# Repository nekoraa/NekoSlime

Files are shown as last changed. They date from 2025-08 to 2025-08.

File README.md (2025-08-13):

# **NekoSlime VR Motion Capture System**

English | [中文](README.zh-CN.md) 

---

## **1. Project Overview**

This project is based on **ESP32 + BMI160 + AK09911C** sensors, compatible with the **SlimeVR protocol**, enabling full-body tracking and virtual reality interaction.

---

## **2. Bill of Materials**

| Item | Quantity | Image |
| --- | --- | --- |
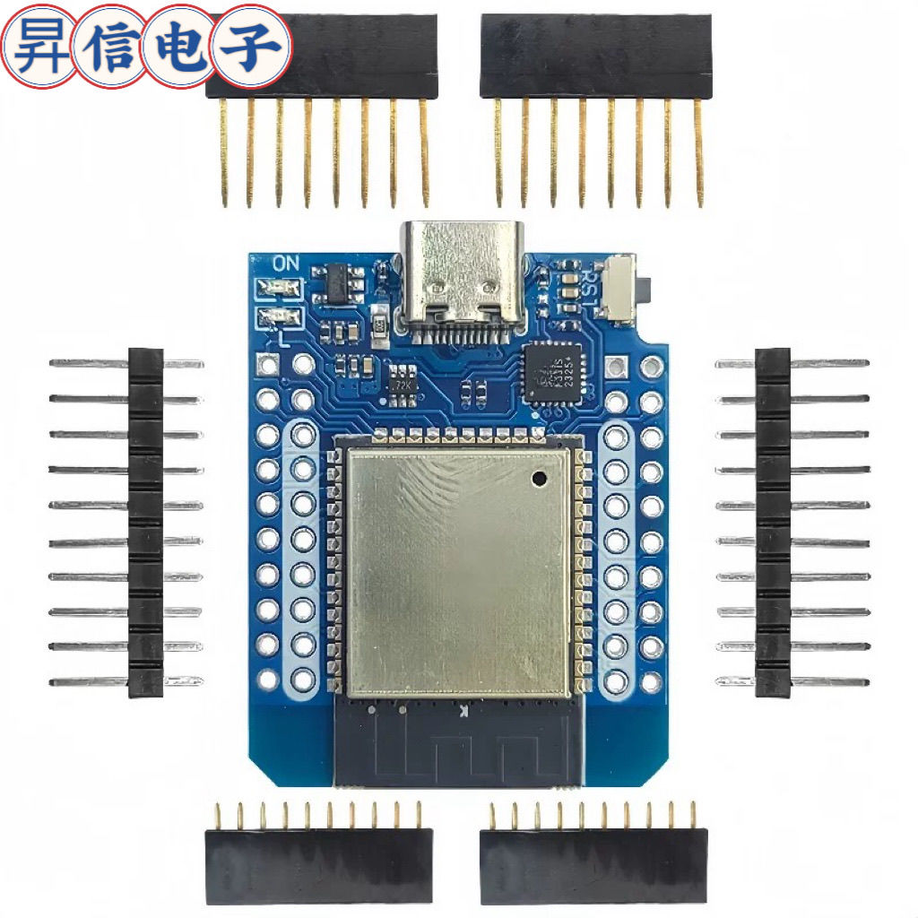
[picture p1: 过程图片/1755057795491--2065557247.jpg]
| ESP32 Mini Board | 6 |  |
| Wires for Soldering | Several  | - |
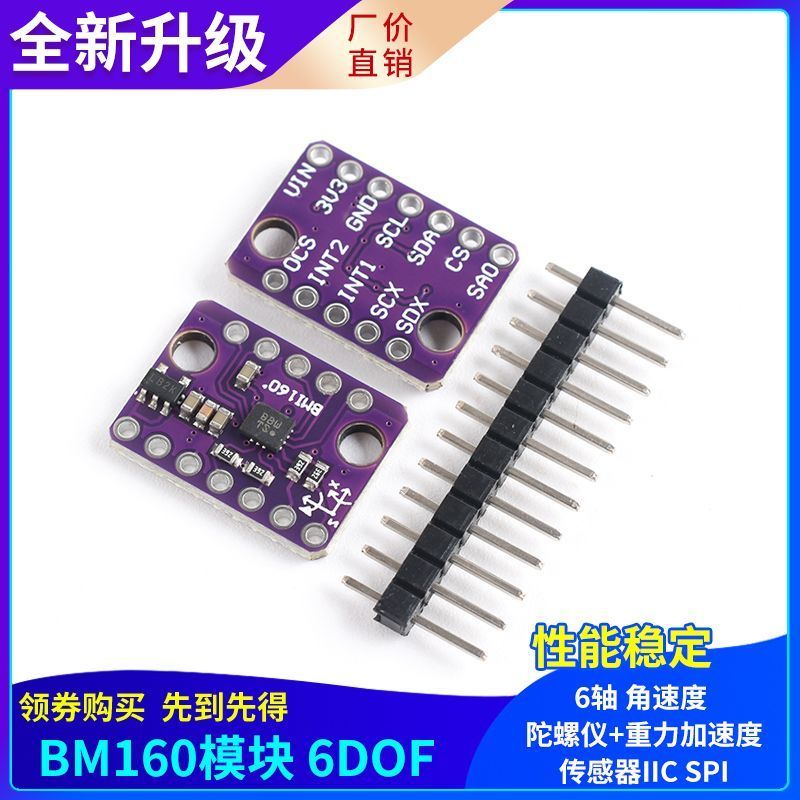
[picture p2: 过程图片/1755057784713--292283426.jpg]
| BMI160 Sensor | 5 |   |
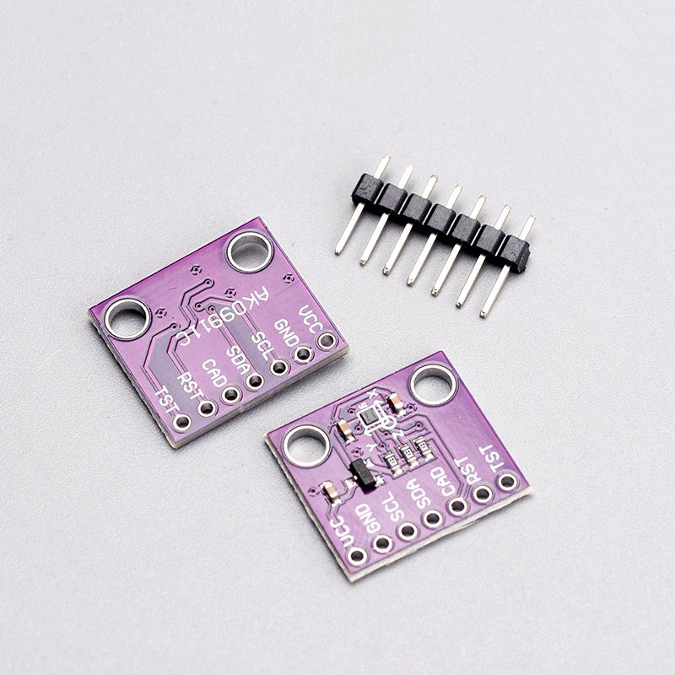
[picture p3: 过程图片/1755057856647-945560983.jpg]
| AK09911C Sensor | 5 |  |
| 3D Printed Case | 5 | - |
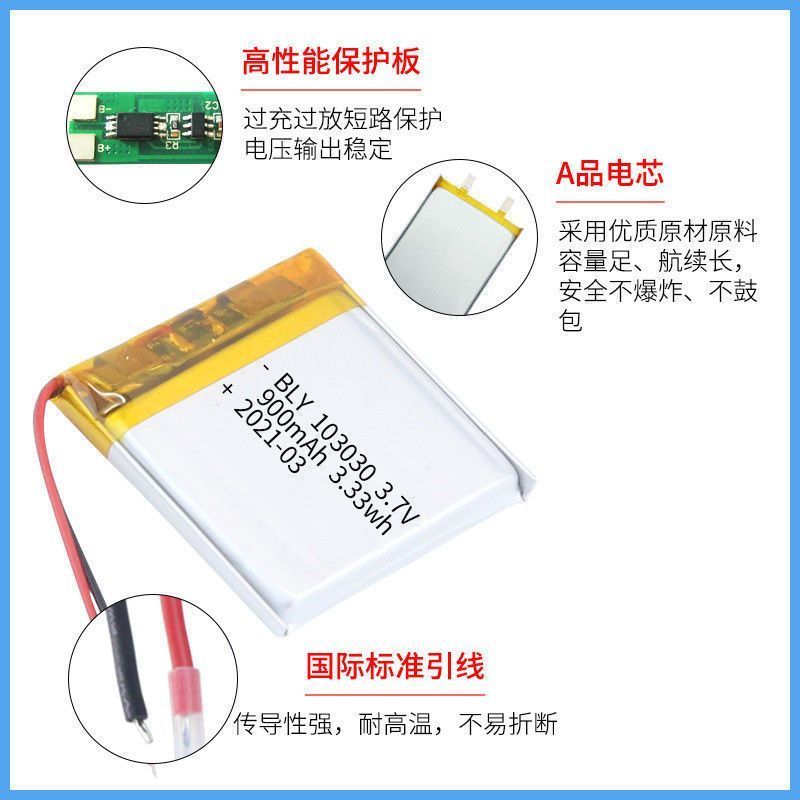
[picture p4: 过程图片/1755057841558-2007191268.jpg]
| Battery | 5 |   |
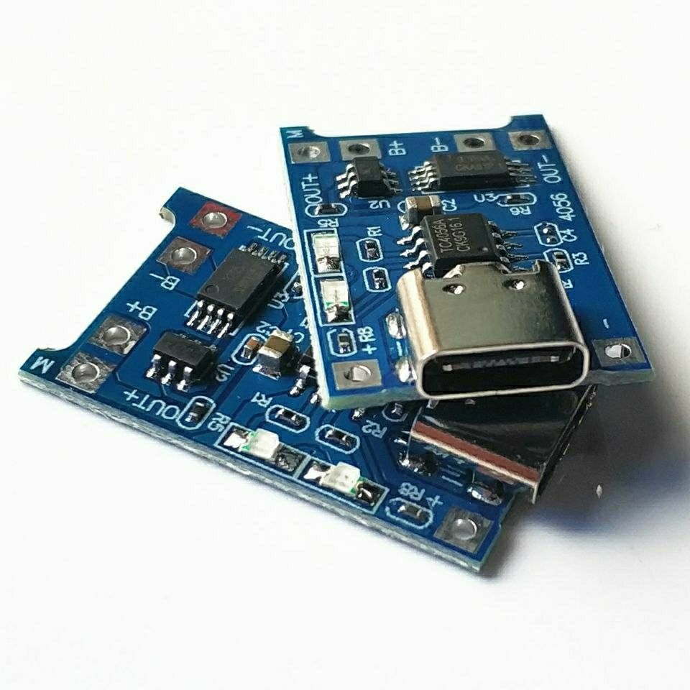
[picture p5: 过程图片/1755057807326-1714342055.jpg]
| Charging Module | 5 |   |
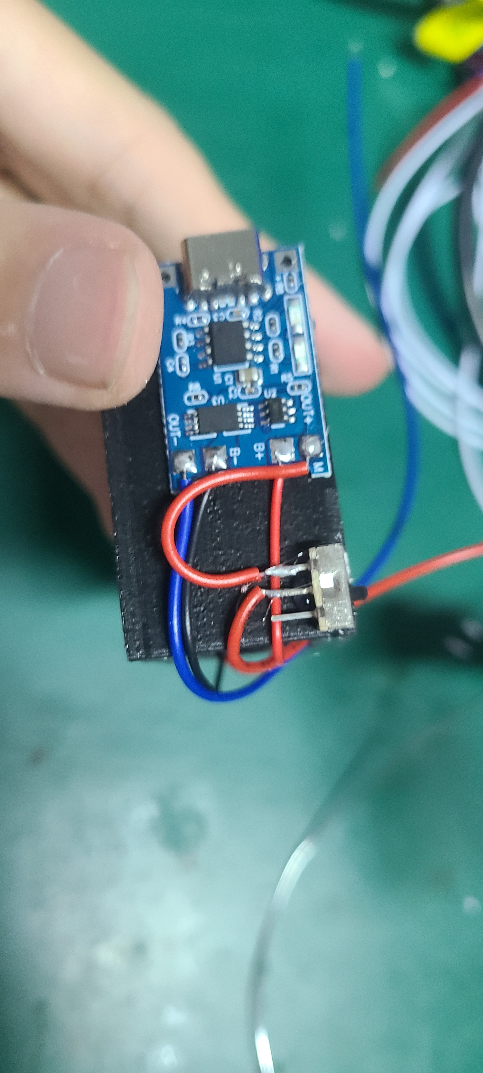
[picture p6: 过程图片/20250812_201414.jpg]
| Switch | 5 |  |

---

## **3. Hardware Connection Steps**

> ⚠ **Note**: The sensors must be aligned strictly as shown in the example to ensure consistent orientation. It is recommended to use thinner jumper wires for easier wiring.

### **3.1 Battery and Charging Module**

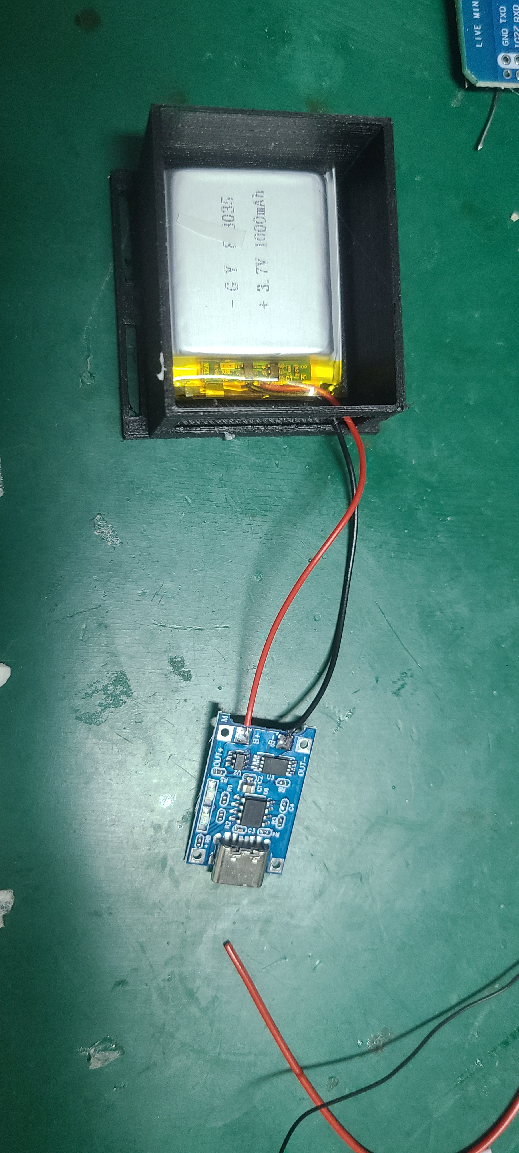
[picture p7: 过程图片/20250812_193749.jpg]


---

### **3.2 Sensor Placement**

* Fix the **BMI160** sensor on the **upper back side of the ESP32** using double-sided tape.
* All sensors must be aligned neatly.

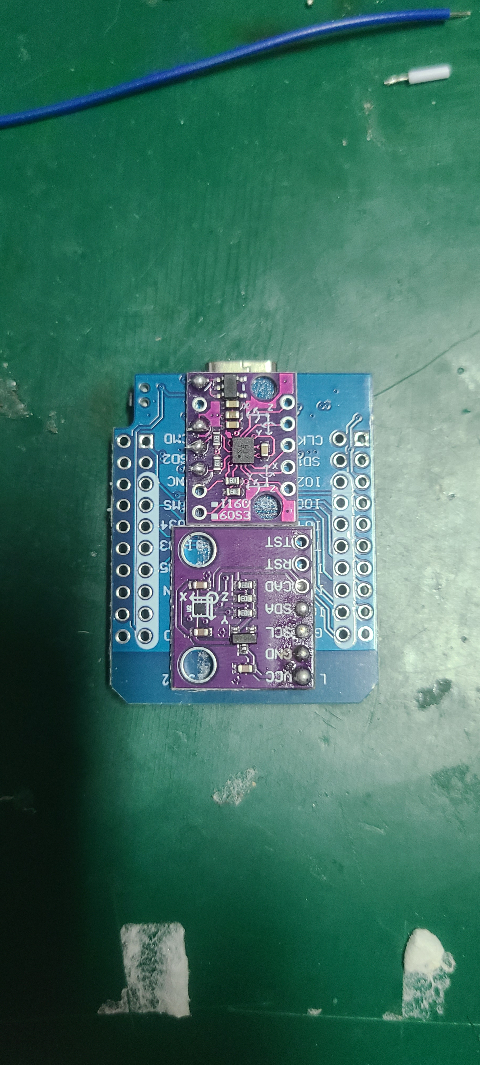
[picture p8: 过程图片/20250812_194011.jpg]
  

---

### **3.3 Sensor Wiring**

1. Connect BMI160 VCC

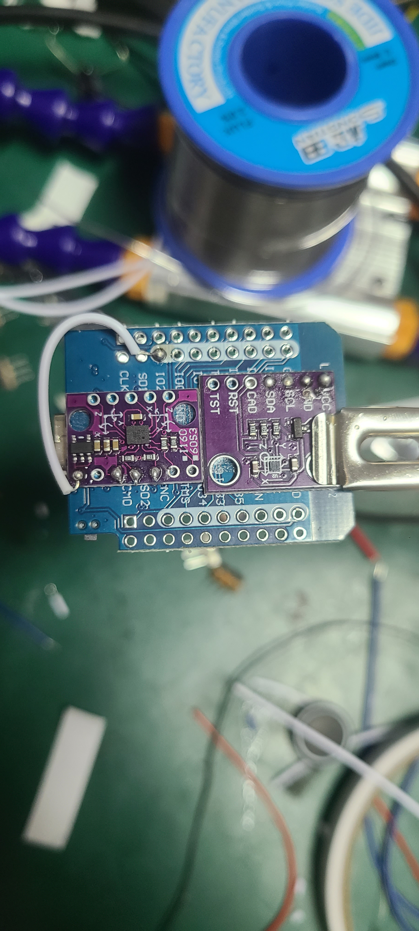
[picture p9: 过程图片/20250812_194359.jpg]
   

2. Connect BMI160 GND

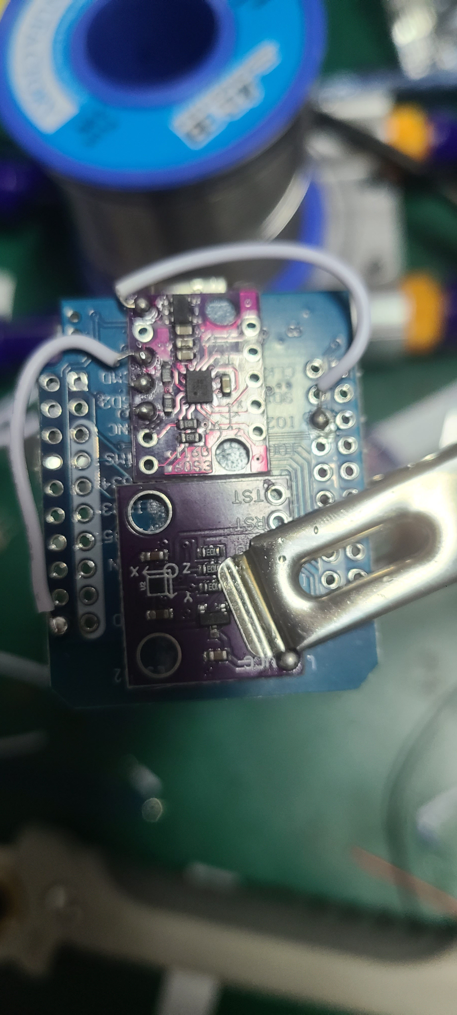
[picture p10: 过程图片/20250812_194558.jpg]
   

3. Connect BMI160 SCL

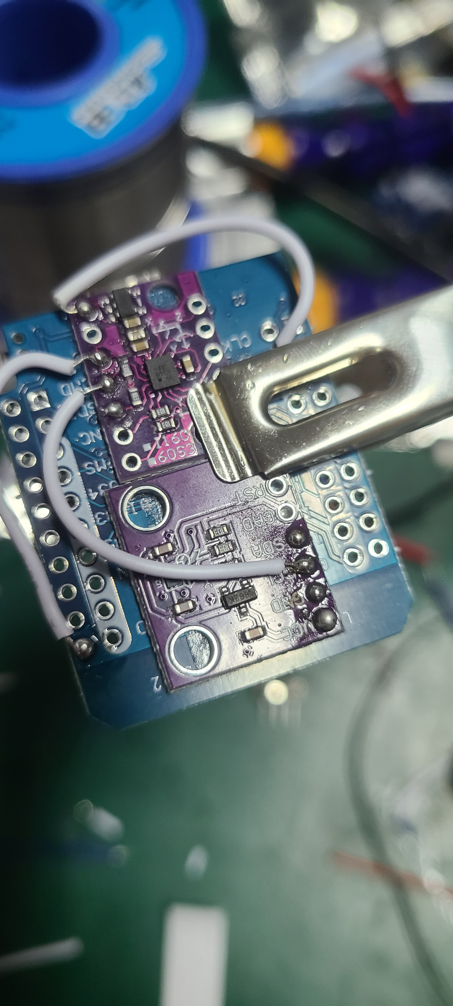
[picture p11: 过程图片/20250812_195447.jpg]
   

4. Connect BMI160 SDA

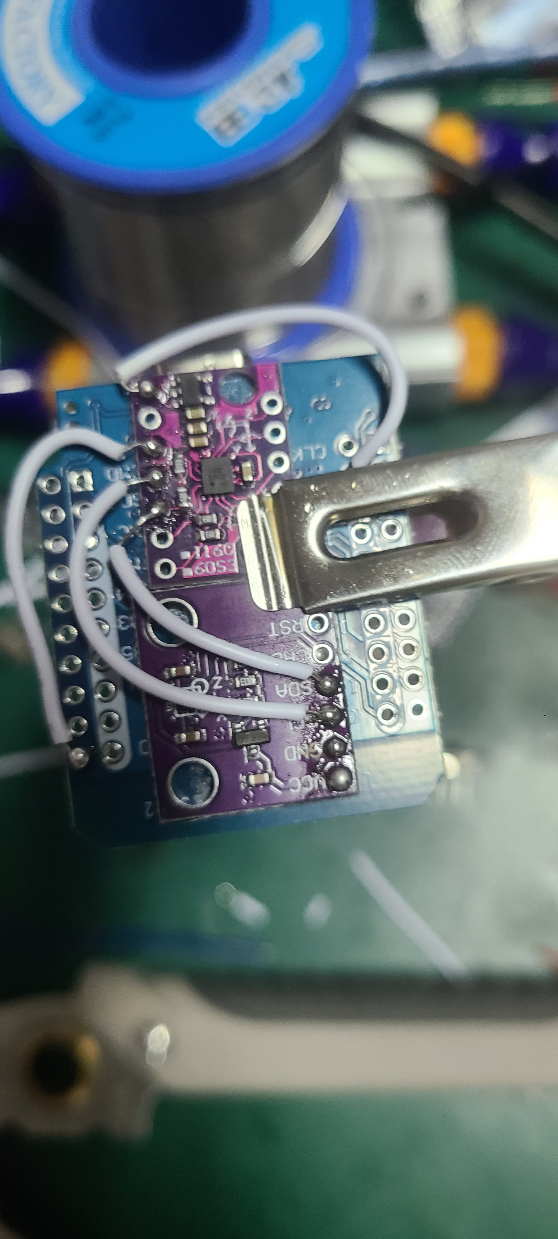
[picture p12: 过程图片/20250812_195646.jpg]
   

5. Connect AK09911C GND

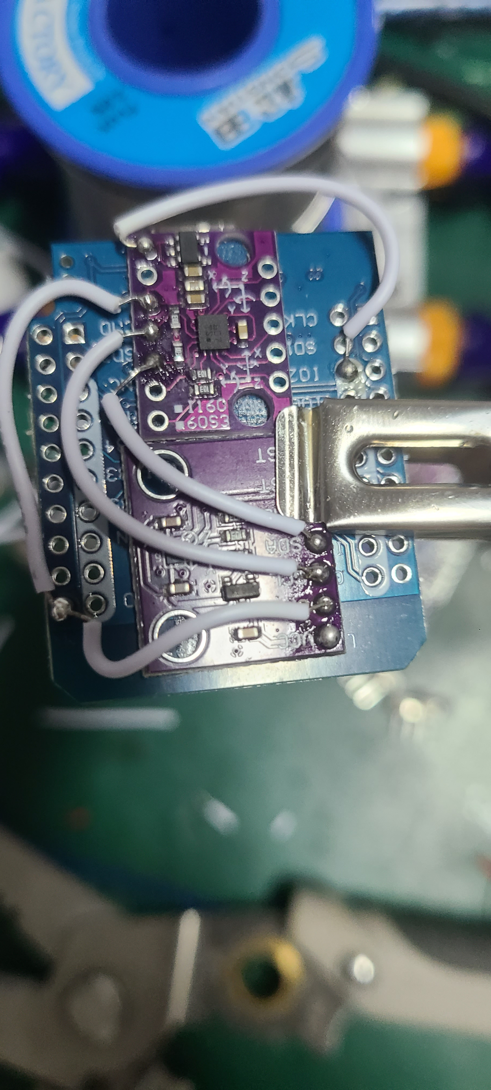
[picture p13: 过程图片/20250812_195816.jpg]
   

6. Connect SCL and SDA to ESP32 GPIO21 (SCL) and GPIO22 (SDA) respectively

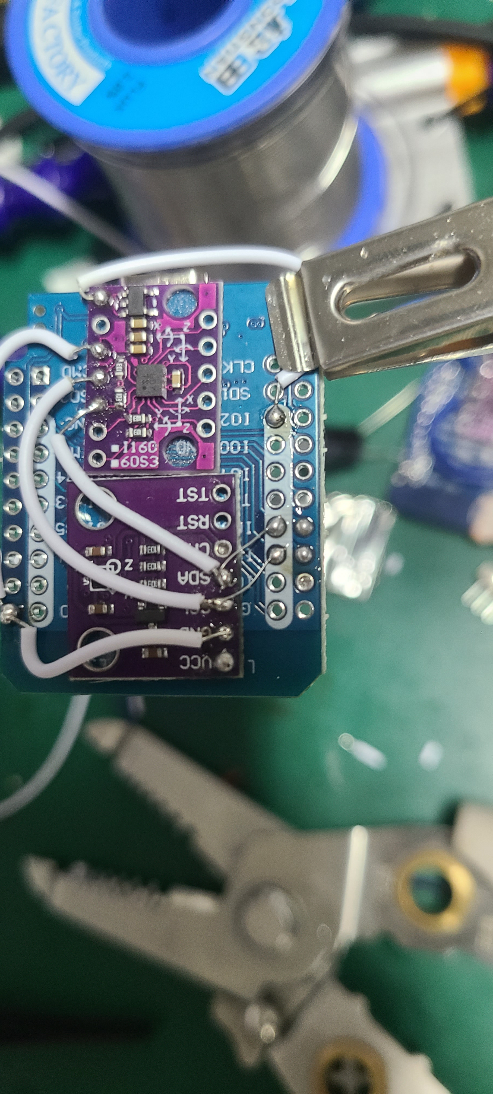
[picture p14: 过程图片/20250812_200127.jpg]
   

7. Connect AK09911C VCC

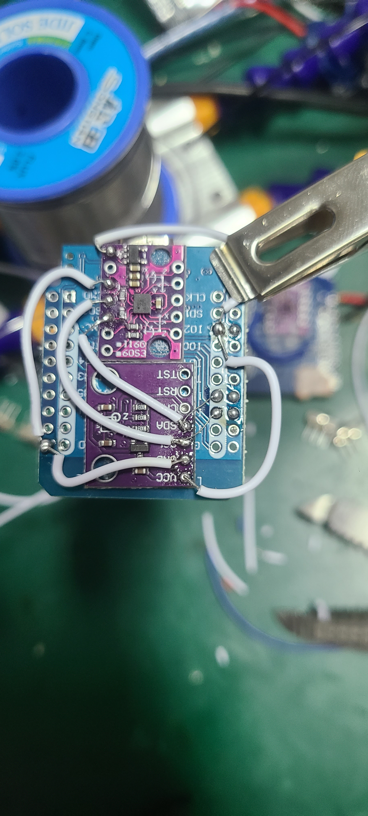
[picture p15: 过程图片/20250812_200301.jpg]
   

8. Connect AK09911C RST to ESP32 3.3V (Very important; otherwise, sensor will not work)

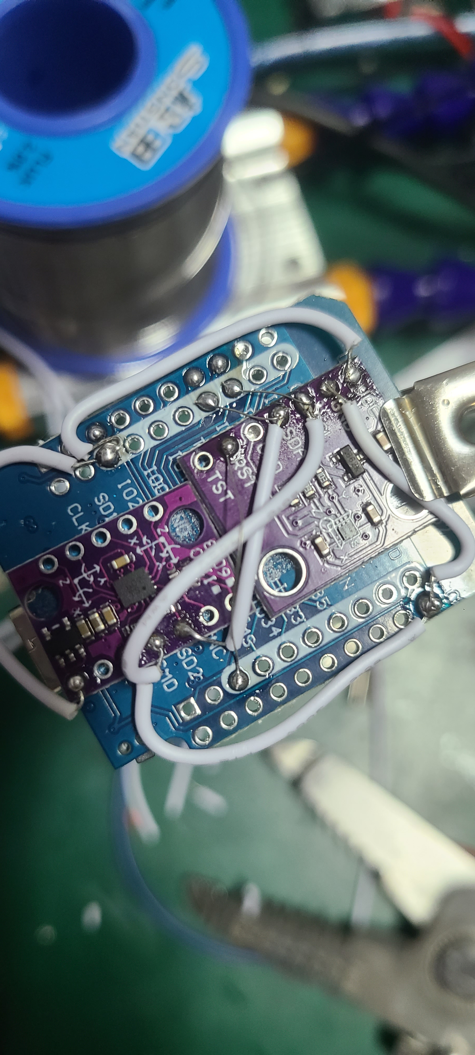
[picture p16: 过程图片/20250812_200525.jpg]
   

---

### **3.4 Final Assembly Check**

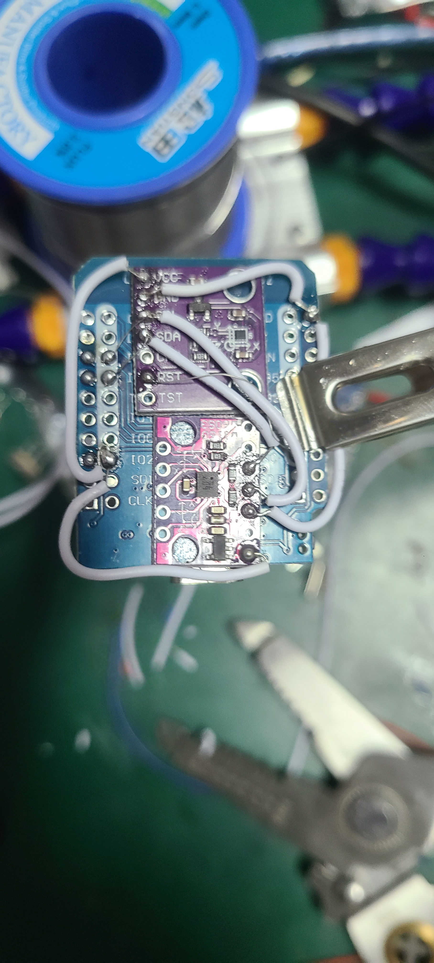
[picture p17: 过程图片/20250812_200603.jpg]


---

### **3.5 Switch and Battery Connection**

* Connect as shown in the picture

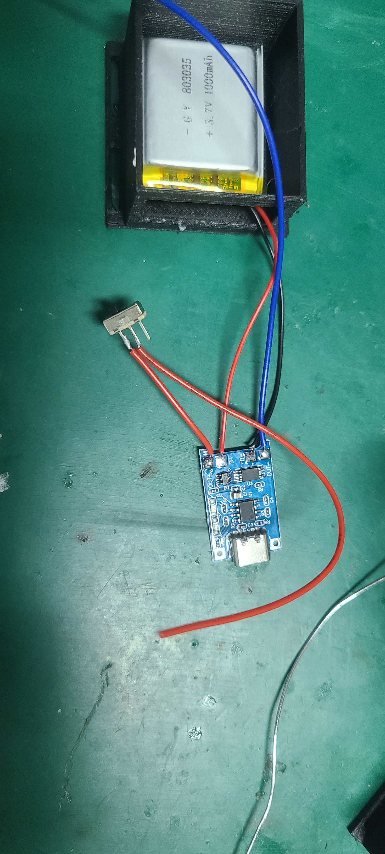
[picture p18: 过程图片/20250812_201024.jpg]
  

---

### **3.6 Fixing the Board**

* Fix the board flat and securely with hot glue as shown

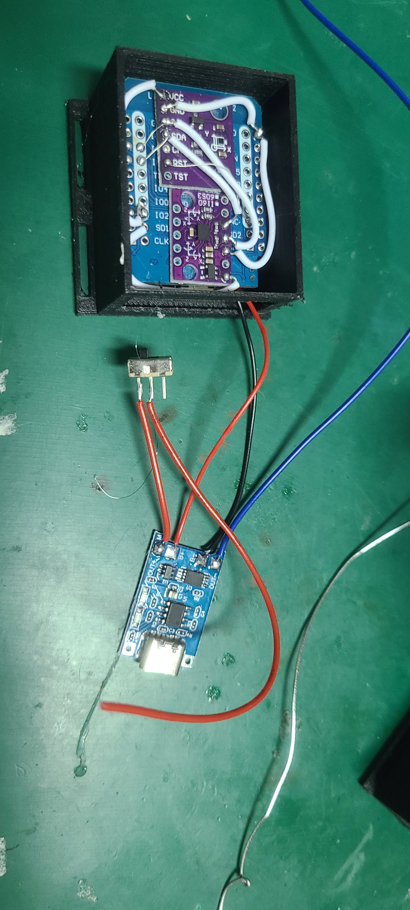
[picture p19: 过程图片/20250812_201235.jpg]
  

---

### **3.7 Charging Module**

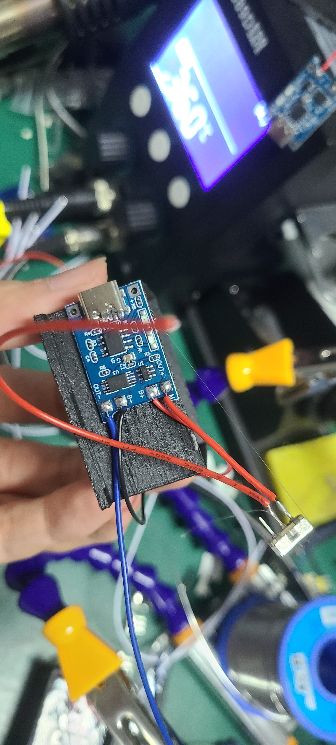
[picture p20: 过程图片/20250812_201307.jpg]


---

### **3.8 Switch**



---

### **3.9 Wiring Red and Blue Wires**

1. Pass red and blue wires through the case

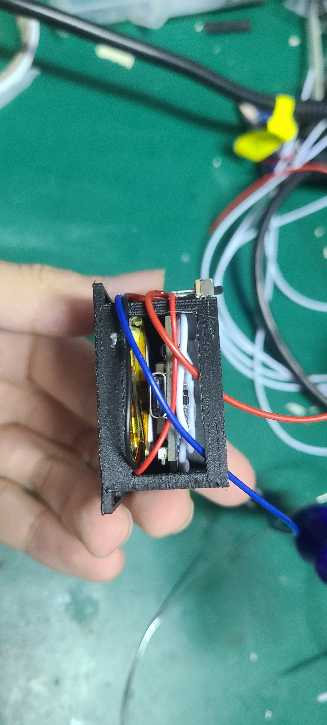
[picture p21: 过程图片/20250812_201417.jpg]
   

2. Connect blue wire to GND

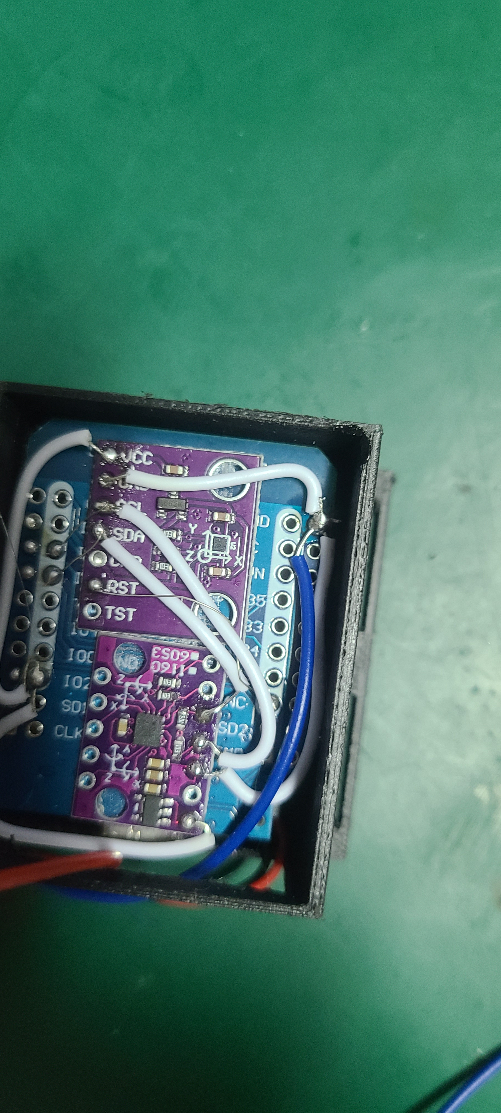
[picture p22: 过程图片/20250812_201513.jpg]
   

3. Connect red wire to VCC

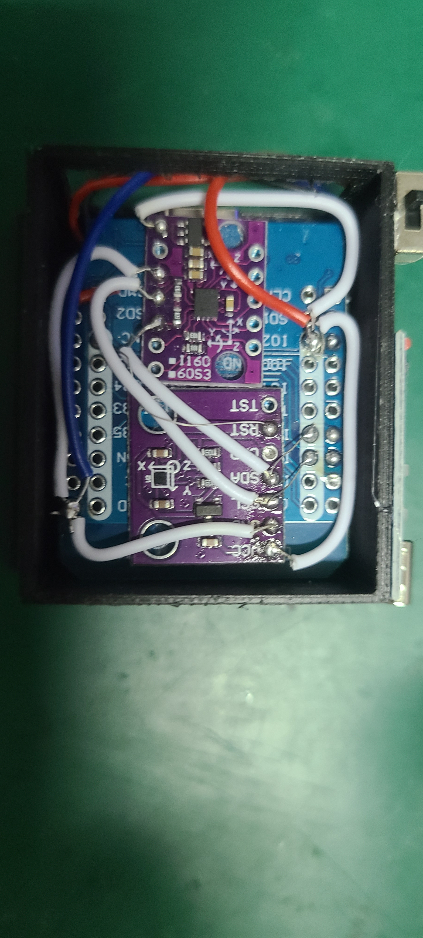
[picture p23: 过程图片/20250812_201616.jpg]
   

---

### **3.10 Complete One Unit**

* Make **6 sets** this way (1 host + 5 slaves)

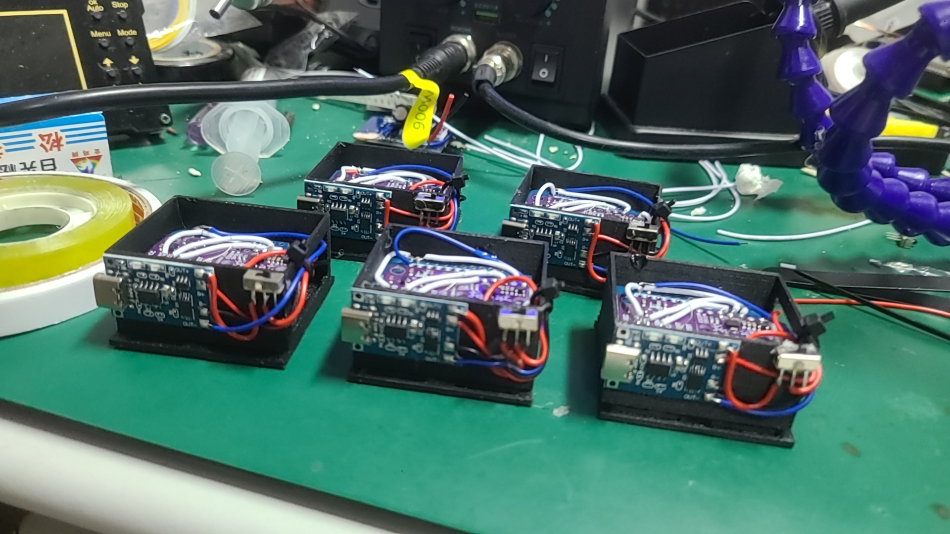
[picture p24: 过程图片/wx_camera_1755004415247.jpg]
  

---

## **4. Firmware Installation**

### **4.1 Install MicroPython**

1. Download and install [Thonny IDE](https://thonny.org/)
2. Download MicroPython firmware ([Download Link](https://micropython.org/download/))

   * Choose **ESP32** version and download the latest stable `.bin` file
3. Connect ESP32 to PC
4. Configure Thonny interpreter:

   * Tools → Options → Interpreter → Select “MicroPython (ESP32)”
   * Select the corresponding COM port
5. Flash the firmware:

   * Click “Install or update MicroPython”
   * Select `.bin` file and flash
6. Repeat for all 6 ESP32s

---

### **4.2 Host ESP32 Setup**

1. Open `host_main.py`
2. Modify Wi-Fi and PC connection settings:

```python
WIFI_SSID = "YourWiFiName"
WIFI_PASSWORD = "YourWiFiPassword"
PC_IP = "PC LAN IP"
PC_PORT = 12345
```

3. Upload `host_main.py` to host ESP32

---

### **4.3 Slave ESP32 Setup**

1. Upload the following files to each slave:

```
ak09911.py
bmi160.py
boot.py
fusion.py
main.py
```

2. Modify `TRACKER_ID` in `main.py` for each slave (0\~4)

---

## **5. PC Software Installation and Usage**

1. Ensure Python is installed on your PC
2. Run:

   * Script: `NekoSlimeReceiver.py`
   * Executable: `dist/NekoSlimeReceiver.exe`
3. Usage order:

   1. Turn on all ESP32 devices
   2. Each slave performs calibration: when blue LED flashes twice, place sensor flat for 10s, then blue LED flashes three times and enters magnetic calibration; move sensor in figure-8 pattern, then LED flashes 4 times and stays on.
   3. Start SlimeVR server
   4. Run NekoSlime receiver and click “Connect”
   5. Check if trackers are connected successfully in SlimeVR

---
# **NekoSlime VR モーションキャプチャーシステム**
---

## **1. プロジェクト概要**

本プロジェクトは **ESP32 + BMI160 + AK09911C** センサーをベースにしており、**SlimeVR プロトコル**に対応し、全身のトラッキングとVRインタラクションを実現します。

---

## **2. 部品リスト**

| 品目 | 数量 | 画像 |
| --- | -- | --- |
| ESP32 ミニボード | 6  |  |
| はんだ付け用ワイヤー | 適量 | - |
| BMI160 センサー | 5  |   |
| AK09911C センサー | 5  |  |
| 3Dプリントケース | 5  | - |
| バッテリー | 5  |   |
| 充電モジュール | 5  |   |
| スイッチ | 5  |  |

---

## **3. ハードウェア接続手順**

> ⚠ **注意**：センサーは必ずサンプルの向きに揃えて取り付けてください。向きが揃っていないと正しい動作ができません。細めのジャンパーワイヤーを使うことを推奨します。

### **3.1 バッテリーと充電モジュール**



---

### **3.2 センサーの配置**

* **BMI160** センサーを **ESP32の背面上部**に両面テープで固定します。
* センサーはすべて綺麗に揃えて配置してください。

  

---

### **3.3 センサー配線**

1. BMI160 VCC を接続

   

2. BMI160 GND を接続

   

3. BMI160 SCL を接続

   

4. BMI160 SDA を接続

   

5. AK09911C GND を接続

   

6. SCL と SDA をそれぞれ ESP32 の GPIO21（SCL）と GPIO22（SDA）に接続

   

7. AK09911C VCC を接続

   

8. AK09911C RST を ESP32 の 3.3V に接続（非常に重要。接続しないと動作しません）

   

---

### **3.4 全体の組み立て確認**



---

### **3.5 スイッチとバッテリーの接続**

* 写真のように接続してください

  

---

### **3.6 ボードの固定**

* ボードは平らにし、ホットボンドでしっかり固定してください。

  

---

### **3.7 充電モジュール**



---

### **3.8 スイッチ**



---

### **3.9 赤と青の配線**

1. 赤と青の線をケースの中に通します。

   

2. 青線をGNDに接続

   

3. 赤線をVCCに接続

   

---

### **3.10 1セット完成**

* この方法で **6セット** 作成してください（1台はホスト、5台はスレーブ）

  

---

## **4. ファームウェアのインストール**

### **4.1 MicroPythonのインストール**

1. [Thonny IDE](https://thonny.org/) をダウンロード・インストール
2. MicroPythonファームウェアをダウンロード（[リンク](https://micropython.org/download/)）

   * **ESP32** 用の最新版の `.bin` ファイルを選択
3. ESP32をPCに接続
4. Thonnyでインタプリタを設定：

   * ツール → オプション → インタプリタ → “MicroPython (ESP32)” を選択
   * 対応するCOMポートを選択
5. ファームウェアを書き込み：

   * “Install or update MicroPython” をクリック
   * `.bin` ファイルを選択して書き込み
6. 6台すべてのESP32で繰り返し

---

### **4.2 ホストESP32の設定**

1. `host_main.py` を開く
2. Wi-FiおよびPC接続設定を変更：

```python
WIFI_SSID = "あなたのWiFi名"
WIFI_PASSWORD = "あなたのWiFiパスワード"
PC_IP = "PCのLAN IPアドレス"
PC_PORT = 12345
```

3. `host_main.py` をホストESP32にアップロード

---

### **4.3 スレーブESP32の設定**

1. 各スレーブに以下のファイルをアップロード：

```
ak09911.py
bmi160.py
boot.py
fusion.py
main.py
```

2. `main.py` 内の `TRACKER_ID` をそれぞれ異なる値（0〜4）に設定

---

## **5. PCソフトのインストールと実行**

1. PCにPythonがインストールされていることを確認
2. 実行方法：

   * スクリプト：`NekoSlimeReceiver.py`
   * 実行ファイル：`dist/NekoSlimeReceiver.exe`
3. 実行手順：

   1. 全てのESP32を電源オン
   2. スレーブはキャリブレーションを実行：青LEDが2回点滅したらセンサーを平置きで10秒間待つ。次に青LEDが3回点滅し、磁気キャリブレーションへ移行。8の字を描くように動かし、完了するとLEDが4回点滅して点灯状態になる。
   3. SlimeVRサーバーを起動
   4. NekoSlime受信プログラムを起動し「接続」ボタンを押す
   5. SlimeVRでトラッカーが接続されているか確認する

---

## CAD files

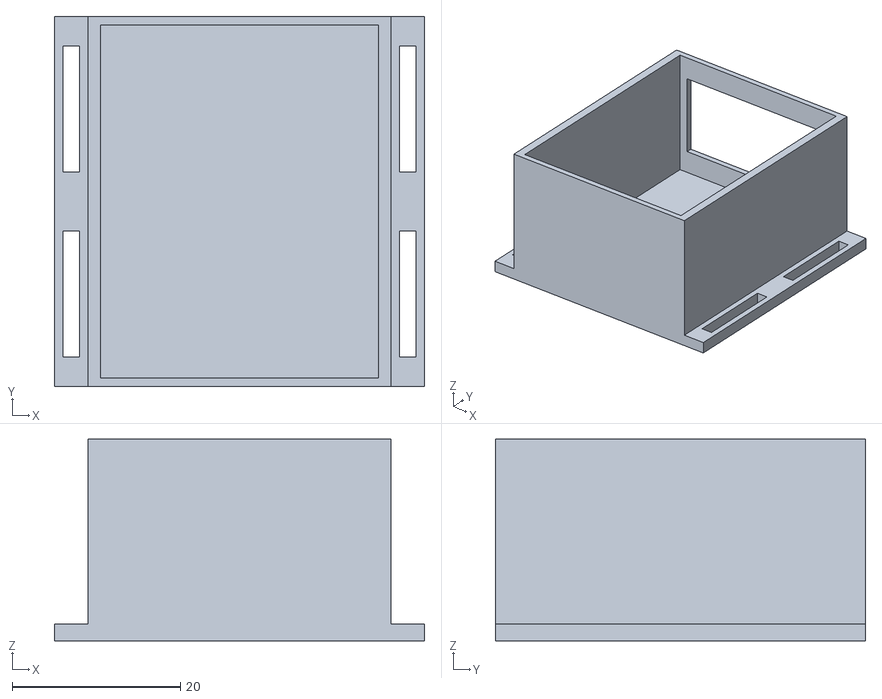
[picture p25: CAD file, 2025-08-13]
零件1.STL
44.0 x 44.0 x 24.0

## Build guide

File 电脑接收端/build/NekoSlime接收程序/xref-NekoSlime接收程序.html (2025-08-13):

# modulegraph cross reference for NekoSlime接收程序.py, pyi_rth__tkinter.py, pyi_rth_inspect.py

NekoSlime接收程序.py Script

imports: _collections_abc • _weakrefset • abc • codecs • collections • collections.abc • copyreg • encodings • encodings.aliases • encodings.ascii • encodings.base64_codec • encodings.big5 • encodings.big5hkscs • encodings.bz2_codec • encodings.charmap • encodings.cp037 • encodings.cp1006 • encodings.cp1026 • encodings.cp1125 • encodings.cp1140 • encodings.cp1250 • encodings.cp1251 • encodings.cp1252 • encodings.cp1253 • encodings.cp1254 • encodings.cp1255 • encodings.cp1256 • encodings.cp1257 • encodings.cp1258 • encodings.cp273 • encodings.cp424 • encodings.cp437 • encodings.cp500 • encodings.cp720 • encodings.cp737 • encodings.cp775 • encodings.cp850 • encodings.cp852 • encodings.cp855 • encodings.cp856 • encodings.cp857 • encodings.cp858 • encodings.cp860 • encodings.cp861 • encodings.cp862 • encodings.cp863 • encodings.cp864 • encodings.cp865 • encodings.cp866 • encodings.cp869 • encodings.cp874 • encodings.cp875 • encodings.cp932 • encodings.cp949 • encodings.cp950 • encodings.euc_jis_2004 • encodings.euc_jisx0213 • encodings.euc_jp • encodings.euc_kr • encodings.gb18030 • encodings.gb2312 • encodings.gbk • encodings.hex_codec • encodings.hp_roman8 • encodings.hz • encodings.idna • encodings.iso2022_jp • encodings.iso2022_jp_1 • encodings.iso2022_jp_2 • encodings.iso2022_jp_2004 • encodings.iso2022_jp_3 • encodings.iso2022_jp_ext • encodings.iso2022_kr • encodings.iso8859_1 • encodings.iso8859_10 • encodings.iso8859_11 • encodings.iso8859_13 • encodings.iso8859_14 • encodings.iso8859_15 • encodings.iso8859_16 • encodings.iso8859_2 • encodings.iso8859_3 • encodings.iso8859_4 • encodings.iso8859_5 • encodings.iso8859_6 • encodings.iso8859_7 • encodings.iso8859_8 • encodings.iso8859_9 • encodings.johab • encodings.koi8_r • encodings.koi8_t • encodings.koi8_u • encodings.kz1048 • encodings.latin_1 • encodings.mac_arabic • encodings.mac_croatian • encodings.mac_cyrillic • encodings.mac_farsi • encodings.mac_greek • encodings.mac_iceland • encodings.mac_latin2 • encodings.mac_roman • encodings.mac_romanian • encodings.mac_turkish • encodings.mbcs • encodings.oem • encodings.palmos • encodings.ptcp154 • encodings.punycode • encodings.quopri_codec • encodings.raw_unicode_escape • encodings.rot_13 • encodings.shift_jis • encodings.shift_jis_2004 • encodings.shift_jisx0213 • encodings.tis_620 • encodings.undefined • encodings.unicode_escape • encodings.utf_16 • encodings.utf_16_be • encodings.utf_16_le • encodings.utf_32 • encodings.utf_32_be • encodings.utf_32_le • encodings.utf_7 • encodings.utf_8 • encodings.utf_8_sig • encodings.uu_codec • encodings.zlib_codec • enum • functools • genericpath • heapq • io • keyword • linecache • locale • ntpath • operator • os • posixpath • pyi_rth__tkinter.py • pyi_rth_inspect.py • re • re._casefix • re._compiler • re._constants • re._parser • reprlib • socket • sre_compile • sre_constants • sre_parse • stat • struct • threading • time • tkinter • tkinter.messagebox • tkinter.ttk • traceback • types • warnings • weakref

pyi_rth__tkinter.py Script

imports: os • sys

imported by: NekoSlime接收程序.py

pyi_rth_inspect.py Script

imports: inspect • os • sys • zipfile

imported by: NekoSlime接收程序.py

_abc (builtin module)

imported by: abc

_ast (builtin module)

imported by: ast

_bisect (builtin module)

imported by: bisect

_blake2 (builtin module)

imported by: hashlib

_bz2 C:\Users\Administrator\.conda\envs\pcb绘制\DLLs\_bz2.pyd

imported by: bz2

_codecs (builtin module)

imported by: codecs

_codecs_cn (builtin module)

imported by: encodings.gb18030 • encodings.gb2312 • encodings.gbk • encodings.hz

_codecs_hk (builtin module)

imported by: encodings.big5hkscs

_codecs_iso2022 (builtin module)

imported by: encodings.iso2022_jp • encodings.iso2022_jp_1 • encodings.iso2022_jp_2 • encodings.iso2022_jp_2004 • encodings.iso2022_jp_3 • encodings.iso2022_jp_ext • encodings.iso2022_kr

_codecs_jp (builtin module)

imported by: encodings.cp932 • encodings.euc_jis_2004 • encodings.euc_jisx0213 • encodings.euc_jp • encodings.shift_jis • encodings.shift_jis_2004 • encodings.shift_jisx0213

_codecs_kr (builtin module)

imported by: encodings.cp949 • encodings.euc_kr • encodings.johab

_codecs_tw (builtin module)

imported by: encodings.big5 • encodings.cp950

_collections (builtin module)

imported by: collections • threading

_collections_abc SourceModule

imports: abc • sys • warnings

imported by: NekoSlime接收程序.py • collections • collections.abc • contextlib • locale • os • pathlib • random • types • weakref

_compat_pickle SourceModule

imported by: _pickle • pickle

_compression SourceModule

imports: io • sys

imported by: bz2 • gzip • lzma

_contextvars (builtin module)

imported by: contextvars

_csv (builtin module)

imported by: csv

_datetime (builtin module)

imports: _strptime • time

imported by: datetime

_decimal C:\Users\Administrator\.conda\envs\pcb绘制\DLLs\_decimal.pyd

imported by: decimal

_frozen_importlib ExcludedModule

imported by: importlib • importlib.abc

_frozen_importlib_external MissingModule

imported by: importlib • importlib._bootstrap • importlib.abc

_functools (builtin module)

imported by: functools

_hashlib C:\Users\Administrator\.conda\envs\pcb绘制\DLLs\_hashlib.pyd

imported by: hashlib

_heapq (builtin module)

imported by: heapq

_imp (builtin module)

imported by: importlib • importlib._bootstrap_external • importlib.util

_io (builtin module)

imported by: importlib._bootstrap_external • io

_locale (builtin module)

imported by: locale

_lzma C:\Users\Administrator\.conda\envs\pcb绘制\DLLs\_lzma.pyd

imported by: lzma

_md5 (builtin module)

imported by: hashlib

_multibytecodec (builtin module)

imported by: encodings.big5 • encodings.big5hkscs • encodings.cp932 • encodings.cp949 • encodings.cp950 • encodings.euc_jis_2004 • encodings.euc_jisx0213 • encodings.euc_jp • encodings.euc_kr • encodings.gb18030 • encodings.gb2312 • encodings.gbk • encodings.hz • encodings.iso2022_jp • encodings.iso2022_jp_1 • encodings.iso2022_jp_2 • encodings.iso2022_jp_2004 • encodings.iso2022_jp_3 • encodings.iso2022_jp_ext • encodings.iso2022_kr • encodings.johab • encodings.shift_jis • encodings.shift_jis_2004 • encodings.shift_jisx0213

_opcode (builtin module)

imported by: opcode

_operator (builtin module)

imported by: operator

_pickle (builtin module)

imports: _compat_pickle • codecs • copyreg

imported by: pickle

_posixsubprocess MissingModule

imports: gc

imported by: subprocess

_py_abc SourceModule

imports: _weakrefset

imported by: abc

_pydatetime SourceModule

imports: _strptime • math • operator • sys • time • warnings

imported by: datetime

_pydecimal SourceModule

imports: collections • contextvars • itertools • locale • math • numbers • re • sys

imported by: decimal

_random (builtin module)

imported by: random

_sha1 (builtin module)

imported by: hashlib

_sha2 (builtin module)

imported by: hashlib • random

_sha3 (builtin module)

imported by: hashlib

_signal (builtin module)

imported by: signal

_socket C:\Users\Administrator\.conda\envs\pcb绘制\DLLs\_socket.pyd

imported by: socket

_sre (builtin module)

imports: copy • re

imported by: re • re._compiler • re._constants

_stat (builtin module)

imported by: stat

_statistics (builtin module)

imported by: statistics

_string (builtin module)

imported by: string

_strptime SourceModule

imports: _thread • calendar • datetime • locale • re • time

imported by: _datetime • _pydatetime • time

_struct (builtin module)

imported by: struct

_thread (builtin module)

imported by: _strptime • dataclasses • functools • reprlib • tempfile • threading

_threading_local SourceModule

imports: contextlib • threading • weakref

imported by: threading

_tkinter C:\Users\Administrator\.conda\envs\pcb绘制\DLLs\_tkinter.pyd

imported by: tkinter

_tokenize (builtin module)

imported by: tokenize

_tracemalloc (builtin module)

imported by: tracemalloc

_typing (builtin module)

imported by: typing

_warnings (builtin module)

imported by: importlib._bootstrap_external • warnings

_weakref (builtin module)

imported by: _weakrefset • collections • weakref

_weakrefset SourceModule

imports: _weakref • types

imported by: NekoSlime接收程序.py • _py_abc • threading • weakref

_winapi (builtin module)

imported by: encodings • ntpath • shutil • subprocess

abc SourceModule

imports: _abc • _py_abc

imported by: NekoSlime接收程序.py • _collections_abc • contextlib • dataclasses • email._policybase • functools • importlib._abc • importlib.abc • importlib.metadata • importlib.resources.abc • inspect • io • numbers • os • selectors • typing

argparse SourceModule

imports: copy • gettext • os • re • shutil • sys • textwrap • warnings

imported by: ast • calendar • dis • gzip • inspect • py_compile • tarfile • tokenize • zipfile

array (builtin module)

imported by: socket

ast SourceModule

imports: _ast • argparse • collections • contextlib • enum • inspect • re • sys • warnings

imported by: inspect • traceback

atexit (builtin module)

imported by: logging • weakref

base64 SourceModule

imports: binascii • getopt • re • struct • sys

imported by: email._encoded_words • email.base64mime • email.encoders • encodings.base64_codec

binascii (builtin module)

imported by: base64 • email._encoded_words • email.base64mime • email.contentmanager • email.header • email.message • encodings.hex_codec • encodings.uu_codec • quopri • zipfile

bisect SourceModule

imports: _bisect

imported by: random • statistics

builtins (builtin module)

imported by: bz2 • codecs • enum • gettext • gzip • inspect • locale • lzma • operator • reprlib • subprocess • tarfile • tokenize • warnings

bz2 SourceModule

imports: _bz2 • _compression • builtins • io • os

imported by: encodings.bz2_codec • shutil • tarfile • zipfile

calendar SourceModule

imports: argparse • datetime • enum • itertools • locale • sys • warnings

imported by: _strptime • email._parseaddr

codecs SourceModule

imports: _codecs • builtins • encodings • sys

imported by: NekoSlime接收程序.py • _pickle • encodings • encodings.ascii • encodings.base64_codec • encodings.big5 • encodings.big5hkscs • encodings.bz2_codec • encodings.charmap • encodings.cp037 • encodings.cp1006 • encodings.cp1026 • encodings.cp1125 • encodings.cp1140 • encodings.cp1250 • encodings.cp1251 • encodings.cp1252 • encodings.cp1253 • encodings.cp1254 • encodings.cp1255 • encodings.cp1256 • encodings.cp1257 • encodings.cp1258 • encodings.cp273 • encodings.cp424 • encodings.cp437 • encodings.cp500 • encodings.cp720 • encodings.cp737 • encodings.cp775 • encodings.cp850 • encodings.cp852 • encodings.cp855 • encodings.cp856 • encodings.cp857 • encodings.cp858 • encodings.cp860 • encodings.cp861 • encodings.cp862 • encodings.cp863 • encodings.cp864 • encodings.cp865 • encodings.cp866 • encodings.cp869 • encodings.cp874 • encodings.cp875 • encodings.cp932 • encodings.cp949 • encodings.cp950 • encodings.euc_jis_2004 • encodings.euc_jisx0213 • encodings.euc_jp • encodings.euc_kr • encodings.gb18030 • encodings.gb2312 • encodings.gbk • encodings.hex_codec • encodings.hp_roman8 • encodings.hz • encodings.idna • encodings.iso2022_jp • encodings.iso2022_jp_1 • encodings.iso2022_jp_2 • encodings.iso2022_jp_2004 • encodings.iso2022_jp_3 • encodings.iso2022_jp_ext • encodings.iso2022_kr • encodings.iso8859_1 • encodings.iso8859_10 • encodings.iso8859_11 • encodings.iso8859_13 • encodings.iso8859_14 • encodings.iso8859_15 • encodings.iso8859_16 • encodings.iso8859_2 • encodings.iso8859_3 • encodings.iso8859_4 • encodings.iso8859_5 • encodings.iso8859_6 • encodings.iso8859_7 • encodings.iso8859_8 • encodings.iso8859_9 • encodings.johab • encodings.koi8_r • encodings.koi8_t • encodings.koi8_u • encodings.kz1048 • encodings.latin_1 • encodings.mac_arabic • encodings.mac_croatian • encodings.mac_cyrillic • encodings.mac_farsi • encodings.mac_greek • encodings.mac_iceland • encodings.mac_latin2 • encodings.mac_roman • encodings.mac_romanian • encodings.mac_turkish • encodings.mbcs • encodings.oem • encodings.palmos • encodings.ptcp154 • encodings.punycode • encodings.quopri_codec • encodings.raw_unicode_escape • encodings.rot_13 • encodings.shift_jis • encodings.shift_jis_2004 • encodings.shift_jisx0213 • encodings.tis_620 • encodings.undefined • encodings.unicode_escape • encodings.utf_16 • encodings.utf_16_be • encodings.utf_16_le • encodings.utf_32 • encodings.utf_32_be • encodings.utf_32_le • encodings.utf_7 • encodings.utf_8 • encodings.utf_8_sig • encodings.uu_codec • encodings.zlib_codec • pickle • tokenize

collections Package

imports: _collections • _collections_abc • _weakref • copy • heapq • itertools • keyword • operator • reprlib • sys

imported by: NekoSlime接收程序.py • _pydecimal • ast • collections.abc • contextlib • dis • email.feedparser • functools • importlib.metadata • importlib.metadata._collections • importlib.resources.readers • inspect • pprint • selectors • shutil • statistics • string • threading • tkinter • tokenize • typing • urllib.parse

collections.abc SourceModule

imports: _collections_abc • collections

imported by: NekoSlime接收程序.py • inspect • logging • selectors • traceback • tracemalloc • typing

contextlib SourceModule

imports: _collections_abc • abc • collections • functools • os • sys • types

imported by: _threading_local • ast • importlib.metadata • importlib.resources._adapters • importlib.resources._common • subprocess • traceback • typing • zipfile._path

contextvars SourceModule

imports: _contextvars

imported by: _pydecimal

copy SourceModule

imports: copyreg • types • weakref

imported by: _sre • argparse • collections • dataclasses • email.generator • gettext • tarfile • weakref

copyreg SourceModule

imports: functools • operator

imported by: NekoSlime接收程序.py • _pickle • copy • pickle • re • typing

csv SourceModule

imports: _csv • io • re • types

imported by: importlib.metadata

dataclasses SourceModule

imports: _thread • abc • copy • functools • inspect • itertools • keyword • re • sys • types

imported by: pprint

datetime SourceModule

imports: _datetime • _pydatetime • time

imported by: _strptime • calendar • email.utils

decimal SourceModule

imports: _decimal • _pydecimal

imported by: fractions • statistics

dis SourceModule

imports: argparse • collections • io • opcode • sys • types

imported by: inspect

email Package

imports: email._header_value_parser • email.charset • email.errors • email.header • email.parser

imported by: email._encoded_words • email._header_value_parser • email._parseaddr • email._policybase • email.base64mime • email.charset • email.contentmanager • email.encoders • email.errors • email.feedparser • email.generator • email.header • email.headerregistry • email.iterators • email.message • email.parser • email.policy • email.quoprimime • email.utils • importlib.metadata

email._encoded_words SourceModule

imports: base64 • binascii • email • email.errors • functools • re • string

imported by: email._header_value_parser • email.message

email._header_value_parser SourceModule

imports: email • email._encoded_words • email.errors • email.utils • operator • re • string • sys • urllib

imported by: email • email.headerregistry

email._parseaddr SourceModule

imports: calendar • email • time

imported by: email.utils

email._policybase SourceModule

imports: abc • email • email.charset • email.header • email.utils

imported by: email.feedparser • email.message • email.parser • email.policy

email.base64mime SourceModule

imports: base64 • binascii • email

imported by: email.charset • email.header

email.charset SourceModule

imports: email • email.base64mime • email.encoders • email.errors • email.quoprimime • functools

imported by: email • email._policybase • email.contentmanager • email.header • email.message • email.utils

email.contentmanager SourceModule

imports: binascii • email • email.charset • email.errors • email.message • email.quoprimime

imported by: email.policy

email.encoders SourceModule

imports: base64 • email • quopri

imported by: email.charset

email.errors SourceModule

imports: email

imported by: email • email._encoded_words • email._header_value_parser • email.charset • email.contentmanager • email.feedparser • email.generator • email.header • email.headerregistry • email.message

email.feedparser SourceModule

imports: collections • email • email._policybase • email.errors • email.message • io • re

imported by: email.parser

email.generator SourceModule

imports: copy • email • email.errors • email.utils • io • random • re • sys • time

imported by: email.message

email.header SourceModule

imports: binascii • email • email.base64mime • email.charset • email.errors • email.quoprimime • re

imported by: email • email._policybase

email.headerregistry SourceModule

imports: email • email._header_value_parser • email.errors • email.utils • types

imported by: email.policy

email.iterators SourceModule

imports: email • io • sys

imported by: email.message

email.message SourceModule

imports: binascii • email • email._encoded_words • email._policybase • email.charset • email.errors • email.generator • email.iterators • email.policy • email.utils • io • quopri • re

imported by: email.contentmanager • email.feedparser • email.policy • importlib.metadata._adapters

email.parser SourceModule

imports: email • email._policybase • email.feedparser • io

imported by: email

email.policy SourceModule

imports: email • email._policybase • email.contentmanager • email.headerregistry • email.message • email.utils • re • sys

imported by: email.message

email.quoprimime SourceModule

imports: email • re • string

imported by: email.charset • email.contentmanager • email.header

email.utils SourceModule

imports: datetime • email • email._parseaddr • email.charset • os • random • re • socket • time • urllib.parse • warnings

imported by: email._header_value_parser • email._policybase • email.generator • email.headerregistry • email.message • email.policy

encodings Package

imports: _winapi • codecs • encodings • encodings.aliases • encodings.ascii • encodings.base64_codec • encodings.big5 • encodings.big5hkscs • encodings.bz2_codec • encodings.charmap • encodings.cp037 • encodings.cp1006 • encodings.cp1026 • encodings.cp1125 • encodings.cp1140 • encodings.cp1250 • encodings.cp1251 • encodings.cp1252 • encodings.cp1253 • encodings.cp1254 • encodings.cp1255 • encodings.cp1256 • encodings.cp1257 • encodings.cp1258 • encodings.cp273 • encodings.cp424 • encodings.cp437 • encodings.cp500 • encodings.cp720 • encodings.cp737 • encodings.cp775 • encodings.cp850 • encodings.cp852 • encodings.cp855 • encodings.cp856 • encodings.cp857 • encodings.cp858 • encodings.cp860 • encodings.cp861 • encodings.cp862 • encodings.cp863 • encodings.cp864 • encodings.cp865 • encodings.cp866 • encodings.cp869 • encodings.cp874 • encodings.cp875 • encodings.cp932 • encodings.cp949 • encodings.cp950 • encodings.euc_jis_2004 • encodings.euc_jisx0213 • encodings.euc_jp • encodings.euc_kr • encodings.gb18030 • encodings.gb2312 • encodings.gbk • encodings.hex_codec • encodings.hp_roman8 • encodings.hz • encodings.idna • encodings.iso2022_jp • encodings.iso2022_jp_1 • encodings.iso2022_jp_2 • encodings.iso2022_jp_2004 • encodings.iso2022_jp_3 • encodings.iso2022_jp_ext • encodings.iso2022_kr • encodings.iso8859_1 • encodings.iso8859_10 • encodings.iso8859_11 • encodings.iso8859_13 • encodings.iso8859_14 • encodings.iso8859_15 • encodings.iso8859_16 • encodings.iso8859_2 • encodings.iso8859_3 • encodings.iso8859_4 • encodings.iso8859_5 • encodings.iso8859_6 • encodings.iso8859_7 • encodings.iso8859_8 • encodings.iso8859_9 • encodings.johab • encodings.koi8_r • encodings.koi8_t • encodings.koi8_u • encodings.kz1048 • encodings.latin_1 • encodings.mac_arabic • encodings.mac_croatian • encodings.mac_cyrillic • encodings.mac_farsi • encodings.mac_greek • encodings.mac_iceland • encodings.mac_latin2 • encodings.mac_roman • encodings.mac_romanian • encodings.mac_turkish • encodings.mbcs • encodings.oem • encodings.palmos • encodings.ptcp154 • encodings.punycode • encodings.quopri_codec • encodings.raw_unicode_escape • encodings.rot_13 • encodings.shift_jis • encodings.shift_jis_2004 • encodings.shift_jisx0213 • encodings.tis_620 • encodings.undefined • encodings.unicode_escape • encodings.utf_16 • encodings.utf_16_be • encodings.utf_16_le • encodings.utf_32 • encodings.utf_32_be • encodings.utf_32_le • encodings.utf_7 • encodings.utf_8 • encodings.utf_8_sig • encodings.uu_codec • encodings.zlib_codec • sys

imported by: NekoSlime接收程序.py • codecs • encodings • encodings.aliases • encodings.ascii • encodings.base64_codec • encodings.big5 • encodings.big5hkscs • encodings.bz2_codec • encodings.charmap • encodings.cp037 • encodings.cp1006 • encodings.cp1026 • encodings.cp1125 • encodings.cp1140 • encodings.cp1250 • encodings.cp1251 • encodings.cp1252 • encodings.cp1253 • encodings.cp1254 • encodings.cp1255 • encodings.cp1256 • encodings.cp1257 • encodings.cp1258 • encodings.cp273 • encodings.cp424 • encodings.cp437 • encodings.cp500 • encodings.cp720 • encodings.cp737 • encodings.cp775 • encodings.cp850 • encodings.cp852 • encodings.cp855 • encodings.cp856 • encodings.cp857 • encodings.cp858 • encodings.cp860 • encodings.cp861 • encodings.cp862 • encodings.cp863 • encodings.cp864 • encodings.cp865 • encodings.cp866 • encodings.cp869 • encodings.cp874 • encodings.cp875 • encodings.cp932 • encodings.cp949 • encodings.cp950 • encodings.euc_jis_2004 • encodings.euc_jisx0213 • encodings.euc_jp • encodings.euc_kr • encodings.gb18030 • encodings.gb2312 • encodings.gbk • encodings.hex_codec • encodings.hp_roman8 • encodings.hz • encodings.idna • encodings.iso2022_jp • encodings.iso2022_jp_1 • encodings.iso2022_jp_2 • encodings.iso2022_jp_2004 • encodings.iso2022_jp_3 • encodings.iso2022_jp_ext • encodings.iso2022_kr • encodings.iso8859_1 • encodings.iso8859_10 • encodings.iso8859_11 • encodings.iso8859_13 • encodings.iso8859_14 • encodings.iso8859_15 • encodings.iso8859_16 • encodings.iso8859_2 • encodings.iso8859_3 • encodings.iso8859_4 • encodings.iso8859_5 • encodings.iso8859_6 • encodings.iso8859_7 • encodings.iso8859_8 • encodings.iso8859_9 • encodings.johab • encodings.koi8_r • encodings.koi8_t • encodings.koi8_u • encodings.kz1048 • encodings.latin_1 • encodings.mac_arabic • encodings.mac_croatian • encodings.mac_cyrillic • encodings.mac_farsi • encodings.mac_greek • encodings.mac_iceland • encodings.mac_latin2 • encodings.mac_roman • encodings.mac_romanian • encodings.mac_turkish • encodings.mbcs • encodings.oem • encodings.palmos • encodings.ptcp154 • encodings.punycode • encodings.quopri_codec • encodings.raw_unicode_escape • encodings.rot_13 • encodings.shift_jis • encodings.shift_jis_2004 • encodings.shift_jisx0213 • encodings.tis_620 • encodings.undefined • encodings.unicode_escape • encodings.utf_16 • encodings.utf_16_be • encodings.utf_16_le • encodings.utf_32 • encodings.utf_32_be • encodings.utf_32_le • encodings.utf_7 • encodings.utf_8 • encodings.utf_8_sig • encodings.uu_codec • encodings.zlib_codec • locale

encodings.aliases SourceModule

imports: encodings

imported by: NekoSlime接收程序.py • encodings • locale

encodings.ascii SourceModule

imports: codecs • encodings

imported by: NekoSlime接收程序.py • encodings

encodings.base64_codec SourceModule

imports: base64 • codecs • encodings

imported by: NekoSlime接收程序.py • encodings

encodings.big5 SourceModule

imports: _codecs_tw • _multibytecodec • codecs • encodings

imported by: NekoSlime接收程序.py • encodings

encodings.big5hkscs SourceModule

imports: _codecs_hk • _multibytecodec • codecs • encodings

imported by: NekoSlime接收程序.py • encodings

encodings.bz2_codec SourceModule

imports: bz2 • codecs • encodings

imported by: NekoSlime接收程序.py • encodings

encodings.charmap SourceModule

imports: codecs • encodings

imported by: NekoSlime接收程序.py • encodings

encodings.cp037 SourceModule

imports: codecs • encodings

imported by: NekoSlime接收程序.py • encodings

encodings.cp1006 SourceModule

imports: codecs • encodings

imported by: NekoSlime接收程序.py • encodings

encodings.cp1026 SourceModule

imports: codecs • encodings

imported by: NekoSlime接收程序.py • encodings

encodings.cp1125 SourceModule

imports: codecs • encodings

imported by: NekoSlime接收程序.py • encodings

encodings.cp1140 SourceModule

imports: codecs • encodings

imported by: NekoSlime接收程序.py • encodings

encodings.cp1250 SourceModule

imports: codecs • encodings

imported by: NekoSlime接收程序.py • encodings

encodings.cp1251 SourceModule

imports: codecs • encodings

imported by: NekoSlime接收程序.py • encodings

encodings.cp1252 SourceModule

imports: codecs • encodings

imported by: NekoSlime接收程序.py • encodings

encodings.cp1253 SourceModule

imports: codecs • encodings

imported by: NekoSlime接收程序.py • encodings

encodings.cp1254 SourceModule

imports: codecs • encodings

imported by: NekoSlime接收程序.py • encodings

encodings.cp1255 SourceModule

imports: codecs • encodings

imported by: NekoSlime接收程序.py • encodings

encodings.cp1256 SourceModule

imports: codecs • encodings

imported by: NekoSlime接收程序.py • encodings

encodings.cp1257 SourceModule

imports: codecs • encodings

imported by: NekoSlime接收程序.py • encodings

encodings.cp1258 SourceModule

imports: codecs • encodings

imported by: NekoSlime接收程序.py • encodings

encodings.cp273 SourceModule

imports: codecs • encodings

imported by: NekoSlime接收程序.py • encodings

encodings.cp424 SourceModule

imports: codecs • encodings

imported by: NekoSlime接收程序.py • encodings

encodings.cp437 SourceModule

imports: codecs • encodings

imported by: NekoSlime接收程序.py • encodings

encodings.cp500 SourceModule

imports: codecs • encodings

imported by: NekoSlime接收程序.py • encodings

encodings.cp720 SourceModule

imports: codecs • encodings

imported by: NekoSlime接收程序.py • encodings

encodings.cp737 SourceModule

imports: codecs • encodings

imported by: NekoSlime接收程序.py • encodings

encodings.cp775 SourceModule

imports: codecs • encodings

imported by: NekoSlime接收程序.py • encodings

encodings.cp850 SourceModule

imports: codecs • encodings

imported by: NekoSlime接收程序.py • encodings

encodings.cp852 SourceModule

imports: codecs • encodings

imported by: NekoSlime接收程序.py • encodings

encodings.cp855 SourceModule

imports: codecs • encodings

imported by: NekoSlime接收程序.py • encodings

encodings.cp856 SourceModule

imports: codecs • encodings

imported by: NekoSlime接收程序.py • encodings

encodings.cp857 SourceModule

imports: codecs • encodings

imported by: NekoSlime接收程序.py • encodings

encodings.cp858 SourceModule

imports: codecs • encodings

imported by: NekoSlime接收程序.py • encodings

encodings.cp860 SourceModule

imports: codecs • encodings

imported by: NekoSlime接收程序.py • encodings

encodings.cp861 SourceModule

imports: codecs • encodings

imported by: NekoSlime接收程序.py • encodings

encodings.cp862 SourceModule

imports: codecs • encodings

imported by: NekoSlime接收程序.py • encodings

encodings.cp863 SourceModule

imports: codecs • encodings

imported by: NekoSlime接收程序.py • encodings

encodings.cp864 SourceModule

imports: codecs • encodings

imported by: NekoSlime接收程序.py • encodings

encodings.cp865 SourceModule

imports: codecs • encodings

imported by: NekoSlime接收程序.py • encodings

encodings.cp866 SourceModule

imports: codecs • encodings

imported by: NekoSlime接收程序.py • encodings

encodings.cp869 SourceModule

imports: codecs • encodings

imported by: NekoSlime接收程序.py • encodings

encodings.cp874 SourceModule

imports: codecs • encodings

imported by: NekoSlime接收程序.py • encodings

encodings.cp875 SourceModule

imports: codecs • encodings

imported by: NekoSlime接收程序.py • encodings

encodings.cp932 SourceModule

imports: _codecs_jp • _multibytecodec • codecs • encodings

imported by: NekoSlime接收程序.py • encodings

encodings.cp949 SourceModule

imports: _codecs_kr • _multibytecodec • codecs • encodings

imported by: NekoSlime接收程序.py • encodings

encodings.cp950 SourceModule

imports: _codecs_tw • _multibytecodec • codecs • encodings

imported by: NekoSlime接收程序.py • encodings

encodings.euc_jis_2004 SourceModule

imports: _codecs_jp • _multibytecodec • codecs • encodings

imported by: NekoSlime接收程序.py • encodings

encodings.euc_jisx0213 SourceModule

imports: _codecs_jp • _multibytecodec • codecs • encodings

imported by: NekoSlime接收程序.py • encodings

encodings.euc_jp SourceModule

imports: _codecs_jp • _multibytecodec • codecs • encodings

imported by: NekoSlime接收程序.py • encodings

encodings.euc_kr SourceModule

imports: _codecs_kr • _multibytecodec • codecs • encodings

imported by: NekoSlime接收程序.py • encodings

encodings.gb18030 SourceModule

imports: _codecs_cn • _multibytecodec • codecs • encodings

imported by: NekoSlime接收程序.py • encodings

encodings.gb2312 SourceModule

imports: _codecs_cn • _multibytecodec • codecs • encodings

imported by: NekoSlime接收程序.py • encodings

encodings.gbk SourceModule

imports: _codecs_cn • _multibytecodec • codecs • encodings

imported by: NekoSlime接收程序.py • encodings

encodings.hex_codec SourceModule

imports: binascii • codecs • encodings

imported by: NekoSlime接收程序.py • encodings

encodings.hp_roman8 SourceModule

imports: codecs • encodings

imported by: NekoSlime接收程序.py • encodings

encodings.hz SourceModule

imports: _codecs_cn • _multibytecodec • codecs • encodings

imported by: NekoSlime接收程序.py • encodings

encodings.idna SourceModule

imports: codecs • encodings • re • stringprep • unicodedata

imported by: NekoSlime接收程序.py • encodings

encodings.iso2022_jp SourceModule

imports: _codecs_iso2022 • _multibytecodec • codecs • encodings

imported by: NekoSlime接收程序.py • encodings

encodings.iso2022_jp_1 SourceModule

imports: _codecs_iso2022 • _multibytecodec • codecs • encodings

imported by: NekoSlime接收程序.py • encodings

encodings.iso2022_jp_2 SourceModule

imports: _codecs_iso2022 • _multibytecodec • codecs • encodings

imported by: NekoSlime接收程序.py • encodings

encodings.iso2022_jp_2004 SourceModule

imports: _codecs_iso2022 • _multibytecodec • codecs • encodings

imported by: NekoSlime接收程序.py • encodings

encodings.iso2022_jp_3 SourceModule

imports: _codecs_iso2022 • _multibytecodec • codecs • encodings

imported by: NekoSlime接收程序.py • encodings

encodings.iso2022_jp_ext SourceModule

imports: _codecs_iso2022 • _multibytecodec • codecs • encodings

imported by: NekoSlime接收程序.py • encodings

encodings.iso2022_kr SourceModule

imports: _codecs_iso2022 • _multibytecodec • codecs • encodings

imported by: NekoSlime接收程序.py • encodings

encodings.iso8859_1 SourceModule

imports: codecs • encodings

imported by: NekoSlime接收程序.py • encodings

encodings.iso8859_10 SourceModule

imports: codecs • encodings

imported by: NekoSlime接收程序.py • encodings

encodings.iso8859_11 SourceModule

imports: codecs • encodings

imported by: NekoSlime接收程序.py • encodings

encodings.iso8859_13 SourceModule

imports: codecs • encodings

imported by: NekoSlime接收程序.py • encodings

encodings.iso8859_14 SourceModule

imports: codecs • encodings

imported by: NekoSlime接收程序.py • encodings

encodings.iso8859_15 SourceModule

imports: codecs • encodings

imported by: NekoSlime接收程序.py • encodings

encodings.iso8859_16 SourceModule

imports: codecs • encodings

imported by: NekoSlime接收程序.py • encodings

encodings.iso8859_2 SourceModule

imports: codecs • encodings

imported by: NekoSlime接收程序.py • encodings

encodings.iso8859_3 SourceModule

imports: codecs • encodings

imported by: NekoSlime接收程序.py • encodings

encodings.iso8859_4 SourceModule

imports: codecs • encodings

imported by: NekoSlime接收程序.py • encodings

encodings.iso8859_5 SourceModule

imports: codecs • encodings

imported by: NekoSlime接收程序.py • encodings

encodings.iso8859_6 SourceModule

imports: codecs • encodings

imported by: NekoSlime接收程序.py • encodings

encodings.iso8859_7 SourceModule

imports: codecs • encodings

imported by: NekoSlime接收程序.py • encodings

encodings.iso8859_8 SourceModule

imports: codecs • encodings

imported by: NekoSlime接收程序.py • encodings

encodings.iso8859_9 SourceModule

imports: codecs • encodings

imported by: NekoSlime接收程序.py • encodings

encodings.johab SourceModule

imports: _codecs_kr • _multibytecodec • codecs • encodings

imported by: NekoSlime接收程序.py • encodings

encodings.koi8_r SourceModule

imports: codecs • encodings

imported by: NekoSlime接收程序.py • encodings

encodings.koi8_t SourceModule

imports: codecs • encodings

imported by: NekoSlime接收程序.py • encodings

encodings.koi8_u SourceModule

imports: codecs • encodings

imported by: NekoSlime接收程序.py • encodings

encodings.kz1048 SourceModule

imports: codecs • encodings

imported by: NekoSlime接收程序.py • encodings

encodings.latin_1 SourceModule

imports: codecs • encodings

imported by: NekoSlime接收程序.py • encodings

encodings.mac_arabic SourceModule

imports: codecs • encodings

imported by: NekoSlime接收程序.py • encodings

encodings.mac_croatian SourceModule

imports: codecs • encodings

imported by: NekoSlime接收程序.py • encodings

encodings.mac_cyrillic SourceModule

imports: codecs • encodings

imported by: NekoSlime接收程序.py • encodings

encodings.mac_farsi SourceModule

imports: codecs • encodings

imported by: NekoSlime接收程序.py • encodings

encodings.mac_greek SourceModule

imports: codecs • encodings

imported by: NekoSlime接收程序.py • encodings

encodings.mac_iceland SourceModule

imports: codecs • encodings

imported by: NekoSlime接收程序.py • encodings

encodings.mac_latin2 SourceModule

imports: codecs • encodings

imported by: NekoSlime接收程序.py • encodings

encodings.mac_roman SourceModule

imports: codecs • encodings

imported by: NekoSlime接收程序.py • encodings

encodings.mac_romanian SourceModule

imports: codecs • encodings

imported by: NekoSlime接收程序.py • encodings

encodings.mac_turkish SourceModule

imports: codecs • encodings

imported by: NekoSlime接收程序.py • encodings

encodings.mbcs SourceModule

imports: codecs • encodings

imported by: NekoSlime接收程序.py • encodings

encodings.oem SourceModule

imports: codecs • encodings

imported by: NekoSlime接收程序.py • encodings

encodings.palmos SourceModule

imports: codecs • encodings

imported by: NekoSlime接收程序.py • encodings

encodings.ptcp154 SourceModule

imports: codecs • encodings

imported by: NekoSlime接收程序.py • encodings

encodings.punycode SourceModule

imports: codecs • encodings

imported by: NekoSlime接收程序.py • encodings

encodings.quopri_codec SourceModule

imports: codecs • encodings • io • quopri

imported by: NekoSlime接收程序.py • encodings

encodings.raw_unicode_escape SourceModule

imports: codecs • encodings

imported by: NekoSlime接收程序.py • encodings

encodings.rot_13 SourceModule

imports: codecs • encodings • sys

imported by: NekoSlime接收程序.py • encodings

encodings.shift_jis SourceModule

imports: _codecs_jp • _multibytecodec • codecs • encodings

imported by: NekoSlime接收程序.py • encodings

encodings.shift_jis_2004 SourceModule

imports: _codecs_jp • _multibytecodec • codecs • encodings

imported by: NekoSlime接收程序.py • encodings

encodings.shift_jisx0213 SourceModule

imports: _codecs_jp • _multibytecodec • codecs • encodings

imported by: NekoSlime接收程序.py • encodings

encodings.tis_620 SourceModule

imports: codecs • encodings

imported by: NekoSlime接收程序.py • encodings

encodings.undefined SourceModule

imports: codecs • encodings

imported by: NekoSlime接收程序.py • encodings

encodings.unicode_escape SourceModule

imports: codecs • encodings

imported by: NekoSlime接收程序.py • encodings

encodings.utf_16 SourceModule

imports: codecs • encodings • sys

imported by: NekoSlime接收程序.py • encodings

encodings.utf_16_be SourceModule

imports: codecs • encodings

imported by: NekoSlime接收程序.py • encodings

encodings.utf_16_le SourceModule

imports: codecs • encodings

imported by: NekoSlime接收程序.py • encodings

encodings.utf_32 SourceModule

imports: codecs • encodings • sys

imported by: NekoSlime接收程序.py • encodings

encodings.utf_32_be SourceModule

imports: codecs • encodings

imported by: NekoSlime接收程序.py • encodings

encodings.utf_32_le SourceModule

imports: codecs • encodings

imported by: NekoSlime接收程序.py • encodings

encodings.utf_7 SourceModule

imports: codecs • encodings

imported by: NekoSlime接收程序.py • encodings

encodings.utf_8 SourceModule

imports: codecs • encodings

imported by: NekoSlime接收程序.py • encodings

encodings.utf_8_sig SourceModule

imports: codecs • encodings

imported by: NekoSlime接收程序.py • encodings

encodings.uu_codec SourceModule

imports: binascii • codecs • encodings • io

imported by: NekoSlime接收程序.py • encodings

encodings.zlib_codec SourceModule

imports: codecs • encodings • zlib

imported by: NekoSlime接收程序.py • encodings

enum SourceModule

imports: builtins • functools • operator • sys • types • warnings

imported by: NekoSlime接收程序.py • ast • calendar • inspect • py_compile • re • signal • socket • tkinter

errno (builtin module)

imported by: gettext • gzip • pathlib • shutil • socket • subprocess • tempfile

fcntl MissingModule

imported by: subprocess

fnmatch SourceModule

imports: functools • os • posixpath • re

imported by: pathlib • shutil • tracemalloc

fractions SourceModule

imports: decimal • functools • math • numbers • operator • re • sys

imported by: statistics

functools SourceModule

imports: _functools • _thread • abc • collections • reprlib • types • typing • weakref

imported by: NekoSlime接收程序.py • contextlib • copyreg • dataclasses • email._encoded_words • email.charset • enum • fnmatch • fractions • importlib.metadata • importlib.metadata._adapters • importlib.metadata._functools • importlib.resources._common • importlib.resources._legacy • inspect • ipaddress • linecache • locale • operator • pathlib • pickle • re • statistics • tempfile • threading • tokenize • tracemalloc • types • typing • urllib.parse

gc (builtin module)

imports: time

imported by: _posixsubprocess • weakref

genericpath SourceModule

imports: os • stat

imported by: NekoSlime接收程序.py • ntpath • posixpath

getopt SourceModule

imports: gettext • os • sys

imported by: base64 • quopri

gettext SourceModule

imports: builtins • copy • errno • locale • operator • os • re • struct • sys • warnings

imported by: argparse • getopt

grp MissingModule

imported by: pathlib • shutil • subprocess • tarfile

gzip SourceModule

imports: _compression • argparse • builtins • errno • io • os • struct • sys • time • warnings • weakref • zlib

imported by: tarfile

hashlib SourceModule

imports: _blake2 • _hashlib • _md5 • _sha1 • _sha2 • _sha3 • logging

imported by: random

heapq SourceModule

imports: _heapq

imported by: NekoSlime接收程序.py • collections

importlib Package

imports: _frozen_importlib • _frozen_importlib_external • _imp • importlib • importlib._bootstrap • importlib._bootstrap_external • importlib.machinery • sys • warnings

imported by: importlib • importlib._abc • importlib._bootstrap • importlib._bootstrap_external • importlib.abc • importlib.machinery • importlib.metadata • importlib.readers • importlib.resources • importlib.resources._common • importlib.util • inspect

importlib._abc SourceModule

imports: abc • importlib • importlib._bootstrap

imported by: importlib.abc • importlib.util

importlib._bootstrap SourceModule

imports: _frozen_importlib_external • importlib

imported by: importlib • importlib._abc • importlib.machinery • importlib.util

importlib._bootstrap_external SourceModule

imports: _imp • _io • _warnings • importlib • importlib.metadata • importlib.readers • marshal • nt • posix • sys • tokenize • winreg

imported by: importlib • importlib.abc • importlib.machinery • importlib.util • py_compile

importlib.abc SourceModule

imports: _frozen_importlib • _frozen_importlib_external • abc • importlib • importlib._abc • importlib._bootstrap_external • importlib.machinery • importlib.resources • importlib.resources.abc • warnings

imported by: importlib.metadata

importlib.machinery SourceModule

imports: importlib • importlib._bootstrap • importlib._bootstrap_external

imported by: importlib • importlib.abc • inspect • py_compile

importlib.metadata Package

imports: abc • collections • contextlib • csv • email • functools • importlib • importlib.abc • importlib.metadata • importlib.metadata._adapters • importlib.metadata._collections • importlib.metadata._functools • importlib.metadata._itertools • importlib.metadata._meta • inspect • itertools • operator • os • pathlib • posixpath • re • sys • textwrap • typing • warnings • zipfile

imported by: importlib._bootstrap_external • importlib.metadata • importlib.metadata._adapters • importlib.metadata._collections • importlib.metadata._functools • importlib.metadata._itertools • importlib.metadata._meta • importlib.metadata._text

importlib.metadata._adapters SourceModule

imports: email.message • functools • importlib.metadata • importlib.metadata._text • re • textwrap • warnings

imported by: importlib.metadata

importlib.metadata._collections SourceModule

imports: collections • importlib.metadata

imported by: importlib.metadata

importlib.metadata._functools SourceModule

imports: functools • importlib.metadata • types

imported by: importlib.metadata • importlib.metadata._text

importlib.metadata._itertools SourceModule

imports: importlib.metadata • itertools

imported by: importlib.metadata

importlib.metadata._meta SourceModule

imports: importlib.metadata • typing

imported by: importlib.metadata

importlib.metadata._text SourceModule

imports: importlib.metadata • importlib.metadata._functools • re

imported by: importlib.metadata._adapters

importlib.readers SourceModule

imports: importlib • importlib.resources.readers

imported by: importlib._bootstrap_external

importlib.resources Package

imports: importlib • importlib.resources • importlib.resources._common • importlib.resources._legacy • importlib.resources.abc

imported by: importlib.abc • importlib.resources • importlib.resources._adapters • importlib.resources._common • importlib.resources._itertools • importlib.resources._legacy • importlib.resources.abc • importlib.resources.readers

importlib.resources._adapters SourceModule

imports: contextlib • importlib.resources • importlib.resources.abc • io

imported by: importlib.resources._common

importlib.resources._common SourceModule

imports: contextlib • functools • importlib • importlib.resources • importlib.resources._adapters • importlib.resources.abc • inspect • itertools • os • pathlib • tempfile • types • typing • warnings

imported by: importlib.resources • importlib.resources._legacy

importlib.resources._itertools SourceModule

imports: importlib.resources

imported by: importlib.resources.readers

importlib.resources._legacy SourceModule

imports: functools • importlib.resources • importlib.resources._common • os • pathlib • types • typing • warnings

imported by: importlib.resources

importlib.resources.abc SourceModule

imports: abc • importlib.resources • io • itertools • os • pathlib • typing

imported by: importlib.abc • importlib.resources • importlib.resources._adapters • importlib.resources._common • importlib.resources.readers

importlib.resources.readers SourceModule

imports: collections • importlib.resources • importlib.resources._itertools • importlib.resources.abc • itertools • operator • pathlib • zipfile

imported by: importlib.readers

importlib.util SourceModule

imports: _imp • importlib • importlib._abc • importlib._bootstrap • importlib._bootstrap_external • sys • threading • types

imported by: py_compile • zipfile

inspect SourceModule

imports: abc • argparse • ast • builtins • collections • collections.abc • dis • enum • functools • importlib • importlib.machinery • itertools • keyword • linecache • operator • os • re • sys • token • tokenize • types • weakref

imported by: ast • dataclasses • importlib.metadata • importlib.resources._common • pyi_rth_inspect.py • typing

io SourceModule

imports: _io • abc

imported by: NekoSlime接收程序.py • _compression • bz2 • csv • dis • email.feedparser • email.generator • email.iterators • email.message • email.parser • encodings.quopri_codec • encodings.uu_codec • gzip • importlib.resources._adapters • importlib.resources.abc • logging • lzma • os • pathlib • pickle • pprint • quopri • socket • subprocess • tarfile • tempfile • tokenize • zipfile • zipfile._path

ipaddress SourceModule

imports: functools • re

imported by: urllib.parse

itertools (builtin module)

imported by: _pydecimal • calendar • collections • dataclasses • importlib.metadata • importlib.metadata._itertools • importlib.resources._common • importlib.resources.abc • importlib.resources.readers • inspect • pickle • random • reprlib • statistics • threading • tokenize • traceback • weakref • zipfile._path

keyword SourceModule

imported by: NekoSlime接收程序.py • collections • dataclasses • inspect

linecache SourceModule

imports: functools • os • sys • tokenize

imported by: NekoSlime接收程序.py • inspect • traceback • tracemalloc • warnings

locale SourceModule

imports: _collections_abc • _locale • builtins • encodings • encodings.aliases • functools • os • re • sys • warnings

imported by: NekoSlime接收程序.py • _pydecimal • _strptime • calendar • gettext • subprocess

logging Package

imports: atexit • collections.abc • io • os • pickle • re • string • sys • threading • time • traceback • types • warnings • weakref

imported by: hashlib

lzma SourceModule

imports: _compression • _lzma • builtins • io • os

imported by: shutil • tarfile • zipfile

marshal (builtin module)

imported by: importlib._bootstrap_external

math (builtin module)

imported by: _pydatetime • _pydecimal • fractions • random • selectors • statistics • urllib.parse

msvcrt (builtin module)

imported by: subprocess

nt (builtin module)

imported by: importlib._bootstrap_external • ntpath • os • shutil

ntpath SourceModule

imports: _winapi • genericpath • nt • os • stat • string • sys

imported by: NekoSlime接收程序.py • os • os.path • pathlib

numbers SourceModule

imports: abc

imported by: _pydecimal • fractions • statistics

opcode SourceModule

imports: _opcode

imported by: dis

operator SourceModule

imports: _operator • builtins • functools

imported by: NekoSlime接收程序.py • _pydatetime • collections • copyreg • email._header_value_parser • enum • fractions • gettext • importlib.metadata • importlib.resources.readers • inspect • random • statistics • typing

os SourceModule

imports: _collections_abc • abc • io • nt • ntpath • os.path • posix • posixpath • stat • subprocess • sys • warnings

imported by: NekoSlime接收程序.py • argparse • bz2 • contextlib • email.utils • fnmatch • genericpath • getopt • gettext • gzip • importlib.metadata • importlib.resources._common • importlib.resources._legacy • importlib.resources.abc • inspect • linecache • locale • logging • lzma • ntpath • os.path • pathlib • posixpath • py_compile • pyi_rth__tkinter.py • pyi_rth_inspect.py • random • shutil • socket • subprocess • tarfile • tempfile • threading • tkinter • zipfile

os.path AliasNode

imports: ntpath • os

imported by: os • py_compile • tracemalloc

pathlib SourceModule

imports: _collections_abc • errno • fnmatch • functools • grp • io • ntpath • os • posixpath • pwd • re • stat • sys • urllib.parse • warnings

imported by: importlib.metadata • importlib.resources._common • importlib.resources._legacy • importlib.resources.abc • importlib.resources.readers • zipfile._path

pickle SourceModule

imports: _compat_pickle • _pickle • codecs • copyreg • functools • io • itertools • pprint • re • struct • sys • types

imported by: logging • tracemalloc

posix MissingModule

imports: resource

imported by: importlib._bootstrap_external • os • posixpath • shutil

posixpath SourceModule

imports: genericpath • os • posix • pwd • re • stat • sys

imported by: NekoSlime接收程序.py • fnmatch • importlib.metadata • os • pathlib • zipfile._path

pprint SourceModule

imports: collections • dataclasses • io • re • sys • types

imported by: pickle

pwd MissingModule

imported by: pathlib • posixpath • shutil • subprocess • tarfile

py_compile SourceModule

imports: argparse • enum • importlib._bootstrap_external • importlib.machinery • importlib.util • os • os.path • sys • traceback

imported by: zipfile

quopri SourceModule

imports: binascii • getopt • io • sys

imported by: email.encoders • email.message • encodings.quopri_codec

random SourceModule

imports: _collections_abc • _random • _sha2 • bisect • hashlib • itertools • math • operator • os • statistics • time • warnings

imported by: email.generator • email.utils • statistics • tempfile

re Package

imports: _sre • copyreg • enum • functools • re • re._compiler • re._constants • re._parser • warnings

imported by: NekoSlime接收程序.py • _pydecimal • _sre • _strptime • argparse • ast • base64 • csv • dataclasses • email._encoded_words • email._header_value_parser • email.feedparser • email.generator • email.header • email.message • email.policy • email.quoprimime • email.utils • encodings.idna • fnmatch • fractions • gettext • importlib.metadata • importlib.metadata._adapters • importlib.metadata._text • inspect • ipaddress • locale • logging • pathlib • pickle • posixpath • pprint • re • re._casefix • re._compiler • re._constants • re._parser • sre_compile • sre_constants • sre_parse • string • tarfile • textwrap • tkinter • tokenize • typing • urllib.parse • warnings • zipfile._path • zipfile._path.glob

re._casefix SourceModule

imports: re

imported by: NekoSlime接收程序.py • re._compiler

re._compiler SourceModule

imports: _sre • re • re._casefix • re._constants • re._parser • sys

imported by: NekoSlime接收程序.py • re • sre_compile

re._constants SourceModule

imports: _sre • re

imported by: NekoSlime接收程序.py • re • re._compiler • re._parser • sre_constants

re._parser SourceModule

imports: re • re._constants • unicodedata • warnings

imported by: NekoSlime接收程序.py • re • re._compiler • sre_parse

reprlib SourceModule

imports: _thread • builtins • itertools

imported by: NekoSlime接收程序.py • collections • functools

resource MissingModule

imported by: posix

select C:\Users\Administrator\.conda\envs\pcb绘制\DLLs\select.pyd

imported by: selectors • subprocess

selectors SourceModule

imports: abc • collections • collections.abc • math • select • sys

imported by: socket • subprocess

shutil SourceModule

imports: _winapi • bz2 • collections • errno • fnmatch • grp • lzma • nt • os • posix • pwd • stat • sys • tarfile • warnings • zipfile • zlib

imported by: argparse • tarfile • tempfile • zipfile

signal SourceModule

imports: _signal • enum

imported by: subprocess

socket SourceModule

imports: _socket • array • enum • errno • io • os • selectors • sys

imported by: NekoSlime接收程序.py • email.utils

sre_compile SourceModule

imports: re • re._compiler • warnings

imported by: NekoSlime接收程序.py

sre_constants SourceModule

imports: re • re._constants • warnings

imported by: NekoSlime接收程序.py

sre_parse SourceModule

imports: re • re._parser • warnings

imported by: NekoSlime接收程序.py

stat SourceModule

imports: _stat

imported by: NekoSlime接收程序.py • genericpath • ntpath • os • pathlib • posixpath • shutil • tarfile • zipfile

statistics SourceModule

imports: _statistics • bisect • collections • decimal • fractions • functools • itertools • math • numbers • operator • random • sys

imported by: random

string SourceModule

imports: _string • collections • re

imported by: email._encoded_words • email._header_value_parser • email.quoprimime • logging • ntpath

stringprep SourceModule

imports: unicodedata

imported by: encodings.idna

struct SourceModule

imports: _struct

imported by: NekoSlime接收程序.py • base64 • gettext • gzip • pickle • tarfile • zipfile

subprocess SourceModule

imports: _posixsubprocess • _winapi • builtins • contextlib • errno • fcntl • grp • io • locale • msvcrt • os • pwd • select • selectors • signal • sys • threading • time • types • warnings

imported by: os

sys (builtin module)

imported by: _collections_abc • _compression • _pydatetime • _pydecimal • argparse • ast • base64 • calendar • codecs • collections • contextlib • dataclasses • dis • email._header_value_parser • email.generator • email.iterators • email.policy • encodings • encodings.rot_13 • encodings.utf_16 • encodings.utf_32 • enum • fractions • getopt • gettext • gzip • importlib • importlib._bootstrap_external • importlib.metadata • importlib.util • inspect • linecache • locale • logging • ntpath • os • pathlib • pickle • posixpath • pprint • py_compile • pyi_rth__tkinter.py • pyi_rth_inspect.py • quopri • re._compiler • selectors • shutil • socket • statistics • subprocess • tarfile • tempfile • threading • tkinter • tokenize • traceback • types • typing • warnings • weakref • zipfile

tarfile SourceModule

imports: argparse • builtins • bz2 • copy • grp • gzip • io • lzma • os • pwd • re • shutil • stat • struct • sys • time • warnings • zlib

imported by: shutil

tempfile SourceModule

imports: _thread • errno • functools • io • os • random • shutil • sys • types • warnings • weakref

imported by: importlib.resources._common

textwrap SourceModule

imports: re

imported by: argparse • importlib.metadata • importlib.metadata._adapters • traceback

threading SourceModule

imports: _collections • _thread • _threading_local • _weakrefset • collections • functools • itertools • os • sys • time • traceback • warnings

imported by: NekoSlime接收程序.py • _threading_local • importlib.util • logging • subprocess • zipfile

time (builtin module)

imports: _strptime

imported by: NekoSlime接收程序.py • _datetime • _pydatetime • _strptime • datetime • email._parseaddr • email.generator • email.utils • gc • gzip • logging • random • subprocess • tarfile • threading • zipfile

tkinter Package

imports: _tkinter • collections • enum • os • re • sys • tkinter.constants • tkinter.messagebox • tkinter.ttk • traceback • types

imported by: NekoSlime接收程序.py • tkinter.commondialog • tkinter.constants • tkinter.messagebox • tkinter.ttk

tkinter.commondialog SourceModule

imports: tkinter

imported by: tkinter.messagebox

tkinter.constants SourceModule

imports: tkinter

imported by: tkinter

tkinter.messagebox SourceModule

imports: tkinter • tkinter.commondialog

imported by: NekoSlime接收程序.py • tkinter

tkinter.ttk SourceModule

imports: tkinter

imported by: NekoSlime接收程序.py • tkinter

token SourceModule

imported by: inspect • tokenize

tokenize SourceModule

imports: _tokenize • argparse • builtins • codecs • collections • functools • io • itertools • re • sys • token

imported by: importlib._bootstrap_external • inspect • linecache

traceback SourceModule

imports: ast • collections.abc • contextlib • itertools • linecache • sys • textwrap • unicodedata

imported by: NekoSlime接收程序.py • logging • py_compile • threading • tkinter • warnings

tracemalloc SourceModule

imports: _tracemalloc • collections.abc • fnmatch • functools • linecache • os.path • pickle

imported by: warnings

types SourceModule

imports: _collections_abc • functools • sys

imported by: NekoSlime接收程序.py • _weakrefset • contextlib • copy • csv • dataclasses • dis • email.headerregistry • enum • functools • importlib.metadata._functools • importlib.resources._common • importlib.resources._legacy • importlib.util • inspect • logging • pickle • pprint • subprocess • tempfile • tkinter • typing • urllib.parse

typing SourceModule

imports: _typing • abc • collections • collections.abc • contextlib • copyreg • functools • inspect • operator • re • sys • types • warnings

imported by: functools • importlib.metadata • importlib.metadata._meta • importlib.resources._common • importlib.resources._legacy • importlib.resources.abc

unicodedata C:\Users\Administrator\.conda\envs\pcb绘制\DLLs\unicodedata.pyd

imported by: encodings.idna • re._parser • stringprep • traceback • urllib.parse

urllib Package

imported by: email._header_value_parser • urllib.parse

urllib.parse SourceModule

imports: collections • functools • ipaddress • math • re • types • unicodedata • urllib • warnings

imported by: email.utils • pathlib

warnings SourceModule

imports: _warnings • builtins • linecache • re • sys • traceback • tracemalloc

imported by: NekoSlime接收程序.py • _collections_abc • _pydatetime • argparse • ast • calendar • email.utils • enum • gettext • gzip • importlib • importlib.abc • importlib.metadata • importlib.metadata._adapters • importlib.resources._common • importlib.resources._legacy • locale • logging • os • pathlib • random • re • re._parser • shutil • sre_compile • sre_constants • sre_parse • subprocess • tarfile • tempfile • threading • typing • urllib.parse • zipfile

weakref SourceModule

imports: _collections_abc • _weakref • _weakrefset • atexit • copy • gc • itertools • sys

imported by: NekoSlime接收程序.py • _threading_local • copy • functools • gzip • inspect • logging • tempfile

winreg (builtin module)

imported by: importlib._bootstrap_external

zipfile Package

imports: argparse • binascii • bz2 • importlib.util • io • lzma • os • py_compile • shutil • stat • struct • sys • threading • time • warnings • zipfile._path • zlib

imported by: importlib.metadata • importlib.resources.readers • pyi_rth_inspect.py • shutil • zipfile._path

zipfile._path Package

imports: contextlib • io • itertools • pathlib • posixpath • re • zipfile • zipfile._path.glob

imported by: zipfile • zipfile._path.glob

zipfile._path.glob SourceModule

imports: re • zipfile._path

imported by: zipfile._path

zlib (builtin module)

imported by: encodings.zlib_codec • gzip • shutil • tarfile • zipfile

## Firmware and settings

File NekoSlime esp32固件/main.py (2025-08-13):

# main.py (Tracker)  —— 保留你原有变量名
from machine import Pin, I2C
import time
from bmi160 import BMI160
from ak09911 import AK09911C
from fusion import 在线偏置与磁抑制
import gc
import network
import espnow
import struct

# --- 配置 ---
TRACKER_ID = 4  # 追踪器ID，改成0~4
HOST_MAC = b'\xec\xe3\x34\x46\x8f\xec'  # 主机MAC地址，确保准确

# --- 初始化WiFi和信道 ---
wlan = network.WLAN(network.STA_IF)
wlan.active(True)
wlan.config(channel=11)  # 跟主机信道保持一致（你的主机是11）

# --- 初始化ESP-NOW ---
e = espnow.ESPNow()
e.active(True)
# 试着预先 add_peer，不成功也没关系
try:
    e.add_peer(HOST_MAC)
except Exception:
    pass
print(f"ESP-NOW 初始化完成, 追踪器ID: {TRACKER_ID}, 目标主机: {HOST_MAC.hex()}")

# 硬件与 I2C 初始化（GPIO21 SDA, GPIO22 SCL）
LED = Pin(2, Pin.OUT)
i2c = I2C(1, scl=Pin(22), sda=Pin(21))
imu = BMI160(i2c)
mag = AK09911C(i2c)

# 采样参数（可调）
目标频率 = 60.0
采样周期_s = 1.0 / 目标频率
采样周期_us = int(1e6 * 采样周期_s)

# 创建融合器
融合器 = 在线偏置与磁抑制(Kp=0.6, 陀螺偏置学习率=2e-4)

# LED 闪烁函数
def led闪(次数, 持续_ms):
    for _ in range(次数):
        LED.on()
        time.sleep_ms(持续_ms)
        LED.off()
        time.sleep_ms(持续_ms)

# --------- 1) 开机提示并进行陀螺静态校准（10s） ----------
led闪(2, 1000)
print("开始陀螺静态偏置采集 10s，请保持不动...")
gyro_sum = [0.0, 0.0, 0.0]
count = 0
start = time.ticks_ms()
while time.ticks_diff(time.ticks_ms(), start) < 10000:
    ax, ay, az, gx, gy, gz = imu.读取六轴()
    gyro_sum[0] += gx; gyro_sum[1] += gy; gyro_sum[2] += gz
    count += 1
    time.sleep_ms(10)
初始_bias = [gyro_sum[i]/count for i in range(3)]
# 将初始 bias 载入融合器为初值
融合器.gyro_bias = 初始_bias[:]
print("陀螺初始偏置:", 融合器.gyro_bias)

# --------- 2) 磁力计椭球/偏置快速采集（用户画8字 10s） ----------
led闪(3, 500)
print("开始磁力计快速采集 10s，请画8字旋转设备...")
mag_max = [-32768, -32768, -32768]
mag_min = [32767, 32767, 32767]
start = time.ticks_ms()
while time.ticks_diff(time.ticks_ms(), start) < 10000:
    mx, my, mz = mag.读取磁力()
    if mx > mag_max[0]: mag_max[0] = mx
    if my > mag_max[1]: mag_max[1] = my
    if mz > mag_max[2]: mag_max[2] = mz
    if mx < mag_min[0]: mag_min[0] = mx
    if my < mag_min[1]: mag_min[1] = my
    if mz < mag_min[2]: mag_min[2] = mz
    time.sleep_ms(20)

# 计算简化校准 (每轴 bias 和 scale)
mag_bias = [ (mag_max[i] + mag_min[i]) / 2.0 for i in range(3) ]
mag_scale = [ (mag_max[i] - mag_min[i]) / 2.0 for i in range(3) ]
avg = (mag_scale[0] + mag_scale[1] + mag_scale[2]) / 3.0
for i in range(3):
    if mag_scale[i] != 0:
        mag_scale[i] = avg / mag_scale[i]
    else:
        mag_scale[i] = 1.0

# 将初始地磁场期望设置为当前平均模长，便于动态检测
mx0 = (mag_max[0] + mag_min[0]) / 2.0
my0 = (mag_max[1] + mag_min[1]) / 2.0
mz0 = (mag_max[2] + mag_min[2]) / 2.0
地磁模长 = (mx0*mx0 + my0*my0 + mz0*mz0) ** 0.5
融合器.地磁强度期望 = 地磁模长

print("磁校准偏置:", mag_bias, "缩放:", mag_scale, "地磁模长:", 地磁模长)

# 校准完成，LED 熄灭
led闪(4, 500)
LED.off()
print("校准完成，开始主循环（{}Hz）".format(目标频率))

LED.on()

# ---- 握手与可靠发送参数（可调） ----
HELLO_INTERVAL_MS = 800    # 未连接时 HELLO 发送间隔
SEND_RETRY = 3             # 每帧最大重试次数
ACK_TIMEOUT_MS = 300       # 等待 ACK 超时（用于重发判定）
GC_EACH_FRAMES = 30        # 每多少帧执行一次 gc.collect()
MAX_PENDING = 8            # 最多缓存未被 ACK 的帧数，防止内存占满

# pending_frames: seq -> dict { 'payload': bytes, 'ts': ticks_ms, 'attempts': int }
pending_frames = {}

# 连接状态：当收到主机 OK 时设为 True
connected = False
last_hello_t = time.ticks_ms()

# 非阻塞接收并处理 ACK/OK（在主循环每帧调用）
def process_incoming():
    global connected
    try:
        r = e.recv(0)  # 非阻塞
    except Exception:
        return
    if not r:
        return
    # 兼容多返回格式 (mac, msg) 或 (mac, msg, rssi)
    if isinstance(r, (tuple, list)):
        if len(r) >= 2:
            peer = r[0]; msg = r[1]
        else:
            return
    else:
        return

    # 处理 OK（握手确认）
    if isinstance(msg, (bytes, bytearray)) and msg == b'OK' and peer == HOST_MAC:
        connected = True
        # 确保 peer 存在
        try:
            e.add_peer(HOST_MAC)
        except Exception:
            pass
        # 清旧 pending（可选保留）
        # pending_frames.clear()
        # print once
        print("收到主机 OK，连接建立")
        return

    # 处理 ACK (b'ACK' + seq)
    if isinstance(msg, (bytes, bytearray)) and msg.startswith(b'ACK') and peer == HOST_MAC:
        if len(msg) >= 5:
            try:
                ack_seq = struct.unpack('>H', msg[3:5])[0]
            except Exception:
                return
            if ack_seq in pending_frames:
                # 已确认，清除
                del pending_frames[ack_seq]
                # 可选: print("ACK", ack_seq)
        return

# 非阻塞发送函数：只将 payload 放入 pending 并尝试发送（不阻塞等待 ACK）
def enqueue_and_send(payload, seq):
    # 限制 pending 长度
    if len(pending_frames) >= MAX_PENDING:
        # 最简单策略：丢弃最老的一帧（按插入时间）
        oldest = min(pending_frames.items(), key=lambda x: x[1]['ts'])[0]
        del pending_frames[oldest]
    # 插入 pending
    pending_frames[seq] = { 'payload': payload, 'ts': time.ticks_ms(), 'attempts': 1 }
    # 尝试发送（立即）
    try:
        e.send(HOST_MAC, payload)
    except Exception:
        # 发送失败也保留在 pending，后续帧会重发
        pass

# 周期性重发检查（在主循环每帧调用）
def pending_check_and_resend():
    now = time.ticks_ms()
    to_resend = []
    for seq, info in list(pending_frames.items()):
        # 若超时则重发（并增加 attempts）
        if time.ticks_diff(now, info['ts']) >= ACK_TIMEOUT_MS:
            if info['attempts'] < SEND_RETRY:
                to_resend.append(seq)
            else:
                # 达到最大重试次数，删掉以免无限增长（可选记录日志）
                # print("丢弃帧 seq", seq, "尝试次数", info['attempts'])
                try:
                    del pending_frames[seq]
                except KeyError:
                    pass
    # 执行重发
    for seq in to_resend:
        info = pending_frames.get(seq)
        if not info:
            continue
        try:
            e.send(HOST_MAC, info['payload'])
            pending_frames[seq]['attempts'] += 1
            pending_frames[seq]['ts'] = time.ticks_ms()
        except Exception:
            # 发送失败，下次再试
            pending_frames[seq]['attempts'] += 1
            pending_frames[seq]['ts'] = time.ticks_ms()

# 初始握手不阻塞：在正式主循环前先发送几次 HELLO（快速触达）
for _ in range(3):
    try:
        e.send(HOST_MAC, b'HELLO' + bytes([TRACKER_ID]))
    except Exception:
        pass
    time.sleep_ms(50)

# --------- 主循环：60Hz 读取 -> 校正 -> 融合 -> 打包并入队发送（非阻塞） ----------
next_us = time.ticks_us()
seq = 0
frame_count = 0

while True:
    # 计算到下一帧剩余时间（微秒）
    now_us = time.ticks_us()
    dt_us = time.ticks_diff(next_us, now_us)
    if dt_us > 0:
        # 如果剩余时间大于 2000us，先 sleep 大部分，最后再微调
        if dt_us > 3000:
            time.sleep_ms((dt_us - 1000) // 1000)  # 保守地睡到接近点
        # 精确等待到时刻
        while time.ticks_diff(next_us, time.ticks_us()) > 0:
            # 少量 busy wait，避免占用太多 CPU
            pass

    # 更新下一帧时间点（避免累计误差）
    next_us = time.ticks_add(next_us, 采样周期_us)

    # 处理可能的入站消息（ACK/OK）尽早处理
    process_incoming()

    # 若未连接且到达 HELLO 发送间隔，则发送 HELLO（不阻塞）
    if not connected and time.ticks_diff(time.ticks_ms(), last_hello_t) >= HELLO_INTERVAL_MS:
        try:
            e.send(HOST_MAC, b'HELLO' + bytes([TRACKER_ID]))
        except Exception:
            pass
        last_hello_t = time.ticks_ms()

    # 读取传感器 (I2C 操作)
    ax, ay, az, gx, gy, gz = imu.读取六轴()
    mx_raw, my_raw, mz_raw = mag.读取磁力()

    # 应用磁校准（保留在 Python 层，尽量保持简单）
    mx = (mx_raw - mag_bias[0]) * mag_scale[0]
    my = (my_raw - mag_bias[1]) * mag_scale[1]
    mz = (mz_raw - mag_bias[2]) * mag_scale[2]

    # 获取当前毫秒时间戳
    now_ms = time.ticks_ms()

    # 更新融合器（内部自动做陀螺偏置学习与磁干扰抑制）
    融合器.更新(ax, ay, az, gx, gy, gz, mx, my, mz, 采样周期_s, now_ms)

    # 输出四元数 xyzw
    qx, qy, qz, qw = 融合器.获取四元数_xyzw()

    # 打包数据（带序号）
    seq = (seq + 1) & 0xFFFF
    payload = struct.pack('>BffffH', TRACKER_ID, qx, qy, qz, qw, seq)

    # 入队并立即尝试发送（非阻塞）
    enqueue_and_send(payload, seq)

    # 每帧检查 pending（重发逻辑）与处理入站（ACK）
    process_incoming()
    pending_check_and_resend()

    # 每 GC_EACH_FRAMES 帧执行一次 gc.collect()
    frame_count += 1
    if frame_count >= GC_EACH_FRAMES:
        frame_count = 0
        gc.collect()

    # tiny yield，释放线程片段（必要时可注释）
    # time.sleep_ms(0)

# end of file

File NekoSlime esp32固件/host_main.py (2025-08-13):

# host_main.py (高频版)
import network, espnow, socket, time, gc, struct
import machine

# 【优化1】将CPU频率提升到240MHz以获得最大性能
machine.freq(240000000)
print(f"CPU 主频已设置为: {machine.freq() / 1000000} MHz")

# --- 初始化ESP-NOW ---
wlan_sta = network.WLAN(network.STA_IF)
wlan_sta.active(True)
e = espnow.ESPNow()
e.active(True)
print("ESP-NOW 初始化完成，等待从机数据...")

# --- 初始化WiFi和UDP ---
def 连接WiFi(ssid, password, 尝试次数=10):
    wlan = network.WLAN(network.STA_IF)
    wlan.active(True)
    if not wlan.isconnected():
        print(f"正在连接 WiFi: {ssid} ...")
        wlan.connect(ssid, password)
        for _ in range(尝试次数 * 10):
            if wlan.isconnected():
                print("WiFi 已连接:", wlan.ifconfig())
                return True
            time.sleep(0.1)
        print("WiFi 连接失败")
        return False
    else:
        print("WiFi 已连接:", wlan.ifconfig())
        return True

WIFI_SSID='NEKORAAA'
WIFI_PASSWORD='xxxxxxx'  
PC_IP='192.168.10.3'
PC_PORT=12345

if not 连接WiFi(WIFI_SSID, WIFI_PASSWORD):
    while True: time.sleep(1)

目标地址 = (PC_IP, int(PC_PORT))
udp套接字 = socket.socket(socket.AF_INET, socket.SOCK_DGRAM)

追踪器数据 = {}
追踪器时间 = {}
gc.collect()

TRACKER_TIMEOUT_MS = 2000
CLEAN_INTERVAL_MS = 1000 # 清理周期可以放宽一些
KNOWN_PEERS_LIMIT = 128
known_peers = set()
_last_clean = time.ticks_ms()

def safe_recv_nonblocking():
    try:
        r = e.recv(0)
    except Exception: return None, None
    if not r: return None, None
    if isinstance(r, (tuple, list)) and len(r) >= 2: return r[0], r[1]
    return None, None

print("\n初始化完成，开始高频转发数据...")

# --- 主循环 ---
while True:
    try:
        host, msg = safe_recv_nonblocking()
        if msg:
            # 自动添加Peer的逻辑保持不变
            if host not in known_peers:
                try:
                    e.add_peer(host)
                    known_peers.add(host)
                    print("已添加新 peer:", host.hex())
                except Exception: pass
            
            # 数据处理
            if isinstance(msg, (bytes, bytearray)) and len(msg) >= 17:
                # 【优化2】不再存储和排序，收到数据立即转发
                # 统一裁剪为17字节，确保格式纯净
                udp_payload = msg[:17]
                try:
                    # 直接发送这个独立的、17字节的数据包
                    udp套接字.sendto(udp_payload, 目标地址)
                except Exception as ex:
                    # 在高频下，只在第一次出现错误时打印，避免刷屏
                    print(f"UDP 转发异常: {ex}")

                # 更新时间戳用于超时检测（这个操作很快，可以保留）
                追踪器时间[host] = time.ticks_ms()

                # 如果是新格式，仍然回送ACK，不影响转发
                if len(msg) >= 19:
                    try:
                        seq = struct.unpack('>H', msg[17:19])[0]
                        ack = b'ACK' + struct.pack('>H', seq)
                        e.send(host, ack)
                    except Exception: pass
        
        # --- 超时清理（与数据转发解耦）---
        now = time.ticks_ms()
        if time.ticks_diff(now, _last_clean) >= CLEAN_INTERVAL_MS:
            _last_clean = now
            stale_hosts = [h for h, ts in 追踪器时间.items() if time.ticks_diff(now, ts) > TRACKER_TIMEOUT_MS]
            if stale_hosts:
                for h in stale_hosts:
                    if h in 追踪器时间: del 追踪器时间[h]
                print("清理超时追踪器 (MAC):", [h.hex() for h in stale_hosts])
                # 【优化4】只在低频的清理任务中执行垃圾回收
                gc.collect()

        # 【优化3】移除主循环中的 sleep，让CPU全力运行
        # time.sleep_ms(0) # 或者直接移除

    except Exception as main_ex:
        print("主循环异常:", main_ex)
        time.sleep_ms(200)
